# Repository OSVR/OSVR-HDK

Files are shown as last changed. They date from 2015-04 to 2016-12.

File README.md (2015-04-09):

OSVR HDK production files.

License agreement is as follows:

Module Developer Kit License 

This License (“License”) is offered to you by Razer Inc. and its affiliates (“Razer”), and governs your use of the Module Developer Kit. Please read this License carefully. By clicking “I Accept”, or by using the Module Developer Kit, you accept and agree to this License. This License constitutes a binding agreement between You and Razer. If you do not accept and agree to the License, you may not use the Module Developer Kit.

Definitions: a. Head-mounted Device (“HMD”) means a head-mounted screen device for the purpose of displaying virtual reality or multimedia applications, intended to be used in conjunction with the OSVR Project, as defined in this Agreement;
b. Intellectual Property Rights (“IPR”) means all rights in patents, patent disclosures, rights in designs, copyright, semi-conductor topography rights, integrated circuit layout design rights, utility models, rights in know-how, inventions, technologies, processes, techniques, methods, designs, drawings, plans, data, specifications, research and development, all copies and tangible embodiments or descriptions of any of the foregoing (in whatever form or medium), rights protecting trade secrets and confidential information, and other intellectual property rights, whether registered or unregistered and including applications for registration, and all rights of protection having equivalent or similar effect or character in any part of the world, but excluding any trademark rights;

c. Module Developer Kit (“MDK”) means the MDK made available from time to time by Razer or its licensees to the OSVR Project at www.osvr.com , that includes all drawings, technical specifications, system files, and packaged APIs. Where You utilize a HMD supplied by Razer, that HMD shall fall within the meaning of the MDK. For the avoidance of doubt, any HMD that is not supplied by Razer, or any technology that is not made available on the OSVR Project, is excluded from the meaning of MDK;

d. Module: any device or component that can be coupled to the HMD, but excluding the HMD;

e. Module Interface Technology: the portions of Modules that implement the MDK or are necessary for interoperability with the HMD;

f. “OSVR Project”: means the Open Source Virtual Reality Project made available by Razer that is the open hardware and software platform initiative located at www.osvr.com, for the development of a HMD;

g. Software: means all or any Source Code and Object Code that is made available at www.osvr.com or any other repository notified by Razer;

h. Source Code means the preferred form for making modifications, including but not limited to software source code, documentation source, and configuration files;

i. Object Code means any form resulting from mechanical transformation or translation of a Source Code, including but not limited to compiled object code, generated documentation, and conversions to other media types; and

j. “You” or “Your” means an individual or a legal entity, its subsidiaries or affiliated companies, that is exercising the rights granted by this License.

Subject to the terms and conditions of this License, Razer grants You a limited, worldwide, no-charge, royalty-free, revocable, non-assignable, non-sublicensable and non-exclusive right to use the IPR owned or controlled by Razer that reads on the MDK, the Modules and the Module Interface Technology, or any combinations thereof, for the purposes of:
(a) developing and testing Modules on the OSVR Project; and (b) creating modified works, in accordance with the purposes set out below.

You agree and acknowledge that the MDK, Modules or Module Interface Technology available on the OSVR Project are solely for the purposes of the OSVR Project and Your personal use. You may not use, sell or distribute the MDK, Modules or Module Interface Technology nor the IPR contained therein for any purposes whatsoever, whether for commercial gain or otherwise. Any attempts to do so will automatically terminate this License.

You agree and acknowledge that the IPR in the MDK, Modules or Module Interface Technology made available on the OSVR Project are owned or controlled by Razer or its licensors.

Except for the license granted herein to Razer, its licensees and assignees, You retain all rights to your IPR when you use the MDK. Through your participation in the OSVR Project, You agree to:

a. provide to Razer your IPR in the Modules or any modified works that may read on the MDK, Modules or Module Interface Technology for the OSVR Project. Your failure to comply with this requirement will automatically terminate this License; and b. grant Razer, Razer’s licensees and assignees a limited, worldwide, no-charge, royalty-free, irrevocable, and non-exclusive right to use Your IPR already existing or that may arise in any modified works that may read on the MDK, Modules or Module Interface Technology. You permit Razer to make, use, sell, distribute, modify and create modified works from Your IPR as described herein. Razer may also sub-license rights to other parties to make, use or sell Your IPR that may read on the MDK, Modules or Module Interface Technology as licensed herein.

You agree that You will waive your rights to injunctive or other equitable relief in relation to your IPR as licensed back in the preceding paragraph. You agree to not prevent nor enjoin Razer or any third party in any way from the manufacture, sale, distribution, import or export of any Modules or product or service that meets with the requirements of the MDK, Modules or Module Interface Technology.

Should you threaten or begin proceedings against Razer alleging patent infringement connected to the OSVR Project, the MDK, Modules or Module Interface Technology, Razer will, at its option, suspend or terminate this License granted to you.

Any software, namely Source Code or Object Code that is made available on the OSVR Project is excluded from the terms of this License. Such software will be governed by separate terms and conditions set out elsewhere at www.osvr.com .

You may not use the name of Razer, nor the names of Razer’s licensors, employees or contractors, to endorse or promote any products or services derived from the MDK without Razer’s express and prior written permission.

YOUR USE OF THE MDK AND ALL CONTENTS OF THE OSVR PROJECT SITE IS AND SHALL BE AT YOUR SOLE RISK. THE MDK AND OSVR PROJECT SITE AND ALL CONTENTS THEREON ARE PROVIDED “AS IS” AND WITHOUT EXPRESS OR IMPLIED WARRANTY OF ANY KIND. TO THE MAXIMUM EXTENT PERMITTED BY LAW, RAZER AND THEIR RESPECTIVE OFFICERS, DIRECTORS, EMPLOYEES, LICENSORS AND AGENTS DISCLAIM ALL WARRANTIES, EXPRESS OR IMPLIED, WITH RESPECT TO THE MDK AND OSVR PROJECT SITE, ALL CONTENTS THEREON, AND SUPPORT SERVICES, INCLUDING BUT NOT LIMITED TO ALL IMPLIED WARRANTIES OF MERCHANTABILITY, FITNESS FOR A PARTICULAR PURPOSE, NON-INFRINGEMENT AND TITLE. RAZER MAKES NO WARRANTY AS TO THE ACCURACY OR COMPLETENESS OF THE CONTENTS OF THE MDK OR THE OSVR PROJECT SITE, AND DOES NOT ENDORSE OR ASSUME LIABILITY FOR ANY DATA, PRODUCT OR SERVICE POSTED BY A THIRD PARTY THROUGH THE OSVR PROJECT SITE. RAZER ASSUMES NO LIABILITY OR RESPONSIBILITY FOR ANY BUGS, VIRUSES, OR OTHER MALWARE THAT MAY BE TRANSMITTED TO OR THROUGH THE OSVR PROJECT SITE, FOR ANY ERRORS, MISTAKES OR INACCURACIES IN CONTENT, OR FOR ANY LOSS OR DAMAGE INCURRED THAT RESULTS FROM THE USE OF ANY CONTENT MADE AVAILABLE IN ANY WAY IN THE MDK OR THROUGH THE OSVR PROJECT SITE.

IN NO EVENT SHALL RAZER, THEIR OFFICERS, DIRECTORS, EMPLOYEES, LICENSORS OR AGENTS BE LIABLE TO YOU FOR ANY SPECIAL, INCIDENTAL, INDIRECT, CONSEQUENTIAL OR PUNITIVE DAMAGES WHATSOEVER, INCLUDING THOSE RESULTING FROM LOSS OF USE, DATA OR PROFITS, HOWEVER CAUSED AND REGARDLESS OF THE THEORY OF LIABILITY, ARISING OUT OF OR IN CONNECTION WITH YOUR USE OF OR INABILITY TO USE THE MDK, EVEN IF RAZER HAS BEEN ADVISED OF THE POSSIBILITY OF SUCH DAMAGES. IN NO EVENT WILL RAZER’S LIABILITY EXCEED THE AMOUNT PAID BY YOU FOR A PRODUCT OR SERVICE.

All other intellectual property rights, trademarks and logos not included in the OSVR are expressly excluded from this License. “RAZER”, the Triple Headed Snake Logo, the names of Razer products, and graphics, logos, page headers, button icons, scripts, and service names may be trademarks, registered trademarks, trade dress or domain names of Razer. You may not use the foregoing in any manner that disparages or discredits Razer or is likely to cause confusion among customers. You may not use Razer’s trademarks and/or trade dress in connection with any product or service without Razer’s express written consent.

You agree to indemnify, defend and hold Razer, its affiliates, officers, directors, employees, licensees and agents harmless from and against any claims, actions, suits or proceedings, loss, cost, damages, liability and expense arising out of or relating to:

a. your use of the MDK, including but not limited to Your or any third party’s manufacture, use, sale, offer for sale or distribution of Your Modules; b. any Module you develop on the MDK that infringes the copyright, trademark, trade dress, trade secret, patent or any intellectual property right of any third party, or defames any person or infringes their rights of publicity or privacy; and c. any act or omission by You which is a breach of this License, or violates any law, regulation or rights of a third party.

You agree that Razer reserves the right at any time, and without prior notice, to modify or substitute components of the MDK, or to withdraw the MDK at any time at its sole discretion. Consequently, You acknowledge that future versions of the MDK may be incompatible with Modules developed on previous versions of the MDK.

Razer reserves the right to amend this License at any time, in its sole discretion. We will notify You of any material changes to the License by posting the new License terms on the www.osvr.com site. Please review these License terms regularly for any changes. The date of the last revision appears at the top of the License. Your continued use of the MDK subsequent to any changes to the License terms will signify your acceptance of the revised terms of License for those future MDK releases.

Without prior notice, Razer may terminate Your License if you violate or breach this License, or for any other reason. In the event of termination, the provisions of paragraph 5 shall continue for a period of twelve (12) months from the date of termination, and the provisions of paragraph 18 of this License shall survive.

You agree that the laws of the State of California, without regard to principles of conflict of laws, will govern this License and any dispute of any sort that might arise between you and Razer from your use of the MDK.

Any dispute relating to your use of the MDK shall be submitted to confidential arbitration in San Diego, California, except that, to the extent you have in any manner violated or threatened to violate Razer’s IPR, Razer may seek injunctive or other appropriate relief in any state or federal court, and you consent to exclusive jurisdiction and venue in such courts. Arbitration under this agreement shall be conducted under the rules then prevailing of the American Arbitration Association. The arbitrator's award shall be binding and may be entered as a judgment in any court of competent jurisdiction. To the fullest extent permitted by applicable law, no arbitration under this Agreement shall be joined to an arbitration involving any other party subject to this Agreement, whether through class arbitration proceedings or otherwise.

This License and other legal notices published by Razer at www.osvr.com from time to time shall constitute the entire agreement between You and Razer concerning the MDK. If any of the provisions of this License shall be deemed invalid, void, or for any reason unenforceable, that provision shall be deemed severable and shall not affect the validity and enforceability of any of the remaining provisions of this License, which shall continue in full force and effect. No waiver shall be deemed a further or continuing waiver, and Razer’s failure to assert any right under this License shall not constitute a waiver of such right. You agree that any cause of action arising out of or relating to the MDK must commence within one (1) year after the cause of action arises, and otherwise is permanently barred. You may not assign or transfer this License, but Razer may assign this License without restriction.

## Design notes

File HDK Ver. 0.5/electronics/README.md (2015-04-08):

Electrical files for OSVR Hacker Dev Kit first public release.

It includes:
Allegro Library files
Board files
Schematics in PDF
Complete EE BOM in XLS down to the last capacitor

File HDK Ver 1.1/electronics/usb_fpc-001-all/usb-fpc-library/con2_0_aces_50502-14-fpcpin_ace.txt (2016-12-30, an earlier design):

(DEVICE FILE: CON2_0_ACES_50502-14-FPCPIN_ACE)

PACKAGE 'ACES_50502-14-FPCPIN'
CLASS IC
PINCOUNT 14

PINORDER 'CON2_0_ACES_50502-14-FPCPIN_ACE' 1 10 11 12 13 14 2 3 4 5 6 7 8 9
FUNCTION G1 'CON2_0_ACES_50502-14-FPCPIN_ACE' 1 10 11 12 13 14 2 3 4 5 6 7 8 9

PACKAGEPROP PART_NAME CON2_0
PACKAGEPROP VALUE ACES_14PIN_FPC

END

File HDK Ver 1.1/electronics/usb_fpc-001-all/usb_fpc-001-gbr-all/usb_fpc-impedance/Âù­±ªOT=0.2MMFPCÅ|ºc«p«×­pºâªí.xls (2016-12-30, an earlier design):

板厚計算 | FPC＆手指疊構厚度計算表
料號： |  | 制令號： |  |  |  |  | 阻抗
 |  | 層別 | 手指1 | 結構圖 | 手指2 | FPC厚度(um) | Single End |  | Differential
 |  |  |  |  |  |  |  |  |  | 90+/-10%
 |  | C/L |  |  |  | 12.5
 |  | 膠(AD) |  |  |  | 25
 |  | 鍍銅 |  |  |  | 10
 |  | 銅(CU) |  | L1 |  | 18 |  |  |  | 5/6mil
 |  | 膠(AD) |  |  |  | 20
 |  | 基材(PI) |  |  |  | 25
 |  | 膠(AD) |  |  |  | 20
 |  | 銅(CU) |  | GND |  | 18
 |  | 鍍銅 |  |  |  | 10
 |  | 膠(AD) |  |  |  | 25
 |  | C/L |  |  |  | 12.5
 | 加總 |  |  |  |  | 196 |  | 0 | 0
 |  |  | 確認: |  |  |  |  | 設計:
保存期限：機種結束 |  |  |  |  |  |  |  |  | RDW7300107R01

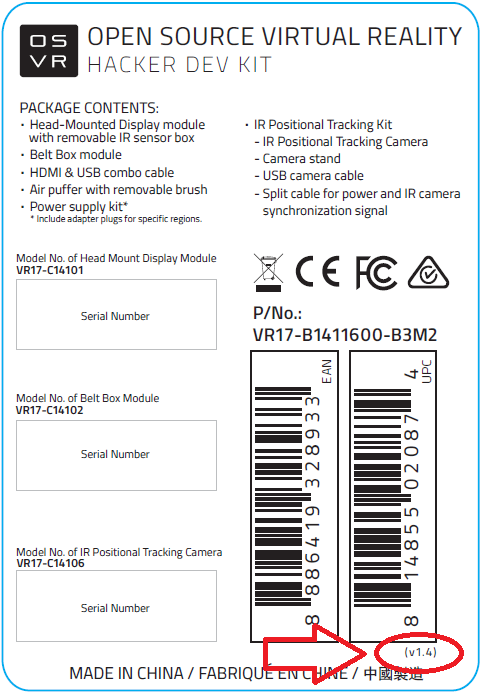
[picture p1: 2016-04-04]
HDK Ver 1.4/misc/1.4 label.png

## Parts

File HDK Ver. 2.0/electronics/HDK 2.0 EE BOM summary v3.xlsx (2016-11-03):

HDK2.0 EE BOM LIST
Description | Vendor | Vendor part number | Location | Category
PCB BARE PCB L:8 MAIN HMD BD 1.7mm FR4 EILEEN HDK TWO PANEL CNNT. | GUITECH | WPC8B8431N000 | NA | HMD board
RES RP 0 OHM 1% 1/16W CHIP #0603 | Ralec | RTT03R000FTP | R1003,R729,R801 | HMD board
RES RP 0 1% 1/10W CHIP #0402 | UniOhm | HP02WAF0000TCE | FB64,FB65,FB68,R1004,R608,R609,R610,R611,R612,R613,R614,R615,R616,R617,R618,R711,R712,R713,R714,R715,R730,R731,R732,R733,R734,R735,R736,R737,R738,R739,R740,R741,R838,R839,R840,R841,R842 | HMD board
RES RP 0 5% 1/8W CHIP #0805 | Ralec | RTT05000JTP | R746 | HMD board
RES RP 0 5% 1/10W 1A #0603 | UniOhm | 0603WAJ0000T5E | R567 | HMD board
RES RP 0 5% 1/10W CHIP #0402 | Ralec | RTH02000JTH | R1001,R107,R1106,R1107,R1108,R1109,R1110,R1111,R1112,R1113,R1114,R1115,R1116,R1117,R1118,R1119,R112,R1120,R1121,R1122,R1123,R1124,R1125,R1126,R1127,R1128,R1129,R113,R1130,R1131,R1132,R1133,R1134,R1135,R1136,R1137,R1138,R1139,R1140,R1141,R1142,R1143,R1144,R1145,R1149,R271,R336,R351,R468,R469,R516,R518,R539,R540,R62,R65,R66,R67,R742,R75,R768,R772,R775,R800,R83,R830,R86 | HMD board
RES RP 100 1% 1/10W CHIP #0402 | UniOhm | HP02WAF1000TCE | R303,R536,R751 | HMD board
RES RP 1K 1% 1/8W CHIP #0805 | Ralec | RTT051001FTP | R743,R745 | HMD board
RES RP 1K 1% 1/10W CHIP #0402 | UniOhm | HP02WAF1001TCE | R1091,R1096,R1097,R1098,R1099,R1103,R1104,R252,R440,R529,R55,R781,R802 | HMD board
RES RP 10K 1% 1/10W CHIP #0603 | UniOhm | 0603WAF1002T5E | R851 | HMD board
RES RP 10K 1% 1/10W CHIP #0402 | UniOhm | HP02WAF1002TCE | R106,R1100,R1101,R1105,R1151,R1152,R1160,R127,R19,R199,R207,R265,R266,R267,R268,R30,R309,R352,R524,R526,R527,R528,R542,R543,R544,R545,R558,R564,R568,R72,R744,R760,R761,R765,R770,R791,R795,R803 | HMD board
RES RP 100K 1% 1/10W CHIP #0603 | UniOhm | 0603WAF1003T5E | R509,R849 | HMD board
RES RP 100K 1% 1/10W CHIP #0402 | UniOhm | HP02WAF1003TCE | R286,R313,R514,R515,R522 | HMD board
RES RP 1M 1% 1/16W CHIP#0402 TA-I | Ralec | RTT021004FTH | R525,R64,R750 | HMD board
RES RP 1M 1% 1/10W CHIP #0603 GREEN | UniOhm | 0603WAF1004T5E | R848 | HMD board
RES RP 12K 1% 1/10W CHIP #0603 | UniOhm | 0603WAF1202T5E | R847 | HMD board | `
RES RP 12K 1% 1/10W CHIP #0402 | UniOhm | HP02WAF1202TCE | R523 | HMD board
RES RP 124K 1% 1/16W CHIP #0402 | Ralec | RTT021243FTH | R565 | HMD board
RES RP 120K 1% 1/10W CHIP #0603 | UniOhm | 0603WAF1203T5E | R846,R850 | HMD board
RES RP 13K 1% 1/10W CHIP #0402 | UniOhm | HP02WAF1302TCE | R91 | HMD board
RES RP 15 1% 1/4W CHIP #1206 | UniOhm | 1206W4F150JT5E | R1094,R1095,R1102 | HMD board
RES RP 150K 1% 1/16W CHIP #0402 | Ralec | RTT021503FTH | R728 | HMD board
RES RP 2K 1% 1/10W CHIP #0603 | UniOhm | 0603WAF2001T5E | R762 | HMD board
RES RP 20K 1% 1/16W CHIP #0402 | Ralec | RTT022002FTH | R1161,R1162,R122,R254,R700,R717,R825,R826 | HMD board
RES RP 20.5K 1% 1/10W CHIP #0402 | UniOhm | HP02WAF2052TCE | R37 | HMD board
RES RP 21.5K 1% 1/16W CHIP #0402 | Ralec | RTT022152FTH | R566 | HMD board
RES RP 2.1M 1% 1/16W CHIP #0402 | Ralec | RTT022104FTH | R510 | HMD board
RES RP 220 1% 1/10W CHIP #0402 | UniOhm | HP02WAF2200TCE | R455 | HMD board
RES RP 232K 1% 1/10W CHIP #0402 | UniOhm | HP02WAF2323TCE | R512 | HMD board
RES RP 24K 1% 1/16W CHIP #0603 "GREEN" | Ralec | RTT032402FTP | R844 | HMD board
RES RP 267K 5% 1/16W #0603 RTT032673FTP RALEC | Ralec | RTT032673FTP | R845 | HMD board
RES RP 33 1% 1/16W CHIP #0603 | UniOhm | 0603WGF330JT5E | R792,R793,R794,R796,R797,R798,R799,R804 | HMD board
RES RP 33 1% 1/10W CHIP #0402 | UniOhm | HP02WAF330JTCE | R115 | HMD board
RES RP 330 1% 1/10W CHIP #0402 | UniOhm | HP02WAF3300TCE | R52 | HMD board
RES RP 45.3K 1% 1/10W CHIP #0402 | UniOhm | HP02WAF4532TCE | R28 | HMD board
RES RP 4.7K 1% 1/10W CHIP #0603 | UniOhm | 0603WAF4701T5E | R220 | HMD board
RES RP 4.7K 1% 1/10W CHIP #0402 | UniOhm | HP02WAF4701TCE | R341,R353,R466,R467,R472,R511,R806,R94,R95,R96 | HMD board
RES RP 47K 1% 1/16W CHIP 0402 | Ralec | RTT024702FTH | R763,R764 | HMD board
RES RP 4.7 1% 1/10W CHIP #0603 | Ralec | RTT034R70FTP | R507,R508 | HMD board
RES RP 49.9 1% 1/10W CHIP #0402 | UniOhm | HP02WAF499JTCE | R1092,R316,R450,R63 | HMD board
RES RP 49.9K 1% 1/10W CHIP #0402 | UniOhm | HP02WAF4992TCE | R1093,R219,R222,R323,R453 | HMD board
RES RP 51K 1% 1/10W CHIP #0402 | UniOhm | HP02WAF5102TCE | R748,R749 | HMD board
RES RP 5R1 1% 1/16W CHIP #0402 | Ralec | RTT025R10FTH | R600,R601,R602,R603,R604,R605,R606,R607 | HMD board
RES RP 68.1K 1% 1/10W CHIP #0402 | UniOhm | HP02WAF6812TCE | R513 | HMD board
RES RP 78.7K 1% 1/16W CHIP #0402 | Ralec | RTT027872FTH | R186,R41,R84 | HMD board
RES RP 8.25K 1% 1/10W CHIP #0402 | UniOhm | HP02WAF8251TCE | R193 | HMD board
CAP CC 10uF 10% 10V X5R CHIP #0603 | YAGEO | CC0603KRX5R6BB106 | C704,C706,C707,C709,C711,C712,C714,C715,C718,C814,C816,C817,C819,C821,C822,C824,C825,C828 | HMD board
CAP CS TANT 10uF ±10% 10V CASE-A 3216-18 T494A106K010AT KEMET | KEMET | T494A106K010AT | C42 | HMD board
CAP CK 10uF 10% 25V X5R CHIP #1206 | YAGEO | CC1206KKX5R8BB106 | C647,C648,C649,C657,C658,C659,C660 | HMD board
CAP CK 10uF ±20% 10V X5R #0603 LMK107BBJ106MALT TAIYO YUDEN | TAIYO YUDEN | LMK107BBJ106MALT | C255,C52,C624,C629,C643,C644,C758 | HMD board
CAP CC 100pF 5% 50V NPO CHIP #0402 | YAGEO | CC0402JRNPO9BN101 | C702,C705,C708,C710,C713,C716,C717,C719,C812,C815,C818,C820,C823,C826,C827,C829 | HMD board
CAP CC 0.01uF 10% 50V X7R #0402 GREEN | YAGEO | CC0402KRX7R9BB103 | C144,C209,C244,C581,C603,C736,C737,C738,C741,C742,C743,C746,C747,C748,C749 | HMD board
CAP CC 0.1uF 10% 16V X7R CHIP #0402 | YAGEO/ WALSIN | CC0402KRX7R7BB104/ 0402B104K160CT | C703,C813 | HMD board
CAP CC 0.1uF 10% 25V X5R #0402 | YAGEO/ WALSIN | CC0402KRX5R8BB104/ 0402X104K250CT | C10,C119,C127,C159,C169,C18,C201,C208,C231,C285,C303,C306,C54,C575,C579,C580,C584,C60,C604,C605,C609,C610,C612,C614,C615,C616,C617,C618,C619,C620,C621,C622,C623,C625,C626,C627,C628,C633,C652,C732,C733,C735,C739,C740,C744,C745,C750,C751,C755,C757,C76,C837,C9 | HMD board
CAP CC 0.1uF 10% 50V X7R #0603 | YAGEO | CC0603KRX7R9BB104 | C100,C145,C175,C2,C220,C28,C602,C632,C761,C762 | HMD board
CAP CK 1Uf 10% 6.3V X5R #0402 | YAGEO | CC0402KRX5R5BB105 | C701,C720,C721,C729,C731,C807,C808,C809 | HMD board
CAP CC 1uF 10% 10V X5R #0402 | YAGEO | CC0402KRX5R6BB105 | C20,C5,C72,C760 | HMD board
CAP CK 1uF 10% 10V X5R CHIP #0603 | YAGEO | CC0603KRX5R6BB105 | C638,C722,C723,C805,C811,C838 | HMD board
CAP CC 1uF 10% 25V X5R #0603 | YAGEO | CC0603KRX5R8BB105 | C653 | HMD board
CAP CK 12PF 5% 50V NPO #0402 | YAGEO | CC0402JRNPO9BN120 | C611 | HMD board
CAP CC 15PF 5% 50V NPO CHIP #0402 | YAGEO | CC0402JRNPO9BN150 | C613 | HMD board
CAP CC 0.015uF ±10% 10V X5R #0402 C0402C153K8PACTU KEMET | KEMET | C0402C153K8PACTU | C157,C298,C545 | HMD board
CAP CC 18pF 5% 50V NPO CHIP #0402 | YAGEO | CC0402JRNPO9BN180 | C31,C32 | HMD board
CAP CK 22uF 10% 10V X7R CHIP #1206 | YAGEO | CC1206KKX7R6BB226 | C654,C655,C726 | HMD board
CAP CK 22uF ±20% 35V X5R #1206 C3216X5R1V226M160AC "TDK" | TDK | C3216X5R1V226M160AC | C1,C3 | HMD board
CAP CS TANT 220uF ±20% 6.3V CASE-B 3528-21 T55B227M6R3C0070 "VISHAY" | VISHAY | T55B227M6R3C0070 | C700,C727,C728 | HMD board
CAP CC 22pF 5% 50V NPO #0603 | YAGEO | CC0603JRNPO9BN220 | C650,C830,C836 | HMD board
CAP CC 2200pF 10% 50V X7R CHIP #0402 | YAGEO | CC0402KRX7R9BB222 | C645,C646 | HMD board
CAP CK 2700pF 10% 50V X7R #0402 | YAGEO | CC0402KRX7R9BB272 | C25 | HMD board
CAP CC 33pF 5% 50V NPO #0402 "GREEN" | YAGEO | CC0402JRNPO9BN330 | C120,C61 | HMD board
CAP CC 3300pF 10% 50V X7R CHIP #0603 | YAGEO | CC0603KRX7R9BB332/ 0603B332K500CT | C656 | HMD board
CAP CC 390pF 5% 50V NPO #0402 | YAGEO | CC0402JRNPO9BN391 | C123,C19,C67 | HMD board
CAP CK 47uF 20% 6.3V X5R CHIP #0805 "Murata" GRM21BR60J476ME15L | Murata | GRM21BR60J476ME15L | C111,C113,C29,C36,C49,C51 | HMD board
CAP CK 47uF ±20% 10V X5R #1206 LMK316ABJ476ML-T TAIYO YUDEN | TAIYO YUDEN | LMK316ABJ476ML-T | C1011,C1012,C1013,C1014,C1015,C1016,C104,C108,C129,C34,C38,C41,C43,C6,C81,C833,C834,C835 | HMD board
CAP CC 470pF 5% 50V NPO #0603 | YAGEO | CC0603JRNPO9BN471 | C136 | HMD board
CAP CC 4700PF 10% 50V X7R #0402 | YAGEO | CC0402KRX7R9BB472 | C57 | HMD board
CAP CC 4.7uF 10% 10V X5R CHIP #0402 | YAGEO | CC0402KRX5R6BB475 | C724,C810 | HMD board
CAP CC 56pF 5% 50V NPO CHIP 0402 | YAGEO | CC0402JRNPO9BN560 | C23 | HMD board
CAP CC 8200pF 10% 25V X7R #0402 | YAGEO | CC0402KRX7R8BB822 | C116 | HMD board
INDUCTOR COMMON MODE CHOKE COIL 90OHM 150mA DLP11SA900HL2L SMD "MURATA" | MURATA | DLP11SA900HL2L | L21,L22 | HMD board
INDUCTOR BEAD 100±25% Ohm 2.5A PBY160808T-101Y-N CHILISIN #0603 | 奇力新 | PBY160808T-101Y-N | FB11,FB23,FB24,FB4,FB62,FB63,FB66,FB67,FB70,FB8 | HMD board
INDUCTOR BEAD 80±25% Ohm 5A GMLB-201209-0080P-N8B MAGLAYERS #0805 | 美磊 | GMLB-201209-0080P-N8B | FB16,FB6,FB7,L23 | HMD board
BEAD UPB321611T-121Y-N 6A 120ohm "CHILISIN" | 奇力新 | UPB321611T-121Y-N | FB1,FB2,FB56,FB61 | HMD board
INDUCTOR 10uH 20% 1A MLH-YT12N100M-O1 "MAGLAYERS" | 美磊 | MLH-YT12N100M-O1 | L31,L34 | HMD board
INDUCTOR POWER SEALED 1.2uH 20% 3.3A LVS404026-1R2,"Chilisin" | 奇力新 | LVS404026-1R2 | L36,L37 | HMD board
INDUCTOR INDCTR 3.3uH 20% 6A MMD-06CZ-3R3M-V1 SMD "MAGLAYERS" | 美磊 | MMD-06CZ-3R3M-V1 | L25 | HMD board
INDUCTOR 4.7uH 20% 1.5A MLV-YT12N4R7M-O1 "MAGLAYERS" | 美磊 | MLV-YT12N4R7M-O1 | L30,L32,L33,L35 | HMD board
INDUCTOR POWER CHOKE 4.7uH 20% 6A MHCI05030-4R7M-R8 "CHILISIN" | 奇力新 | MHCI05030-4R7M-R8 | L13 | HMD board
INDUCTOR POWER CHOKE 5.6uH 20% 4.5A MHCI05020-5R6M-R8 SMD "CHILISIN" | 奇力新 | MHCI05020-5R6M-R8 | L5,L9 | HMD board
FUSE 3A 15V TUV SMD2920P300TF/15 "POLYTRONICS" | Kunshan Polystar Electronics Co.ltd | SMD2920P300TF/15 |  | HMD board
XTAL 8MHz ±30ppm CL=18pF 5*3.2mm SMD E5FA8E000000GE "HOSONIC" | 鴻星 | E5FA8E000000GE | Y1 | HMD board
XTAL 25MHz ±10ppm CL=10pF 3.2*2.5mm SMD E3SB25E00000LE "HOSONIC" | 鴻星 | E3SB25E00000LE | Y6 | HMD board
XTAL SMD CRYSTAL OSCILLATOR 48MHZ 1.8V D3SX48E00000CE 3.2*2.5mm "HOSONIC" | 鴻星 | D3SX48E00000CE | Y7 | HMD board
TRNSTR 2N7002-7-F N-CHANNEL ENHANCEMENT SOT-23 "DIODES" | Diodes | 2N7002-7-F | Q21,Q23,Q41 | HMD board
MOSFET DUAL N-CH 2N7002DW-7-F VDSS/60V VGSS/20V ID/0.115A SOT363 "DIODES" | Diodes | 2N7002DW-7-F | Q29 | HMD board
TRNSTR DMP2160U-7 P-CHANNEL ENHANCEMENT MODE MOSFET SOT-23 | Diodes | DMP2160U-7 | Q33,Q35,Q37 | HMD board
XTOR NPN MMBT2222A-7-F 600mA/40V SOT-23 DIODES | Diodes | MMBT2222A-7-F | Q11,Q32,Q7 | HMD board
TRNSTR MOSFET SIS434DN-T1-GE3 N-CHANNEL 40V (D-S) POWERPAK 1212-8 "VISHAY" | Vishay | SIS434DN-T1-GE3 | Q19,Q20,Q34,Q36,Q38 | HMD board
DIODE SURFACE MOUNT FAST SWITCHING DIODE 75V 1N4148WS-7-F SOD323 DIODES | Diodes | 1N4148WS-7-F | D7 | HMD board
DIODE SCHOTTKY 1N5819HW-7-F 1A/40V SOD123 DIODES | Diodes | 1N5819HW-7-F | D13,D14,D15 | HMD board
DIODE TVS DIOIDE ARRAY 6V 1 CHANNEL LOW CAPACITANCEVS D5V0F1U2LP-7B X1-DFN1006-2 DIODES | Diodes | D5V0F1U2LP-7B | ESD13,ESD14,ESD21 | HMD board
DIODE ZENER MMSZ5227B-7-F 3.42~3.78V SOD-123 DIODES | Diodes | MMSZ5227B-7-F | D6 | HMD board
DIODE ZENER 14.25V~15.75V 0.2W MMSZ5245BS-7-F SOD-323 DIODES | Diodes | MMSZ5245BS-7-F | D9 | HMD board
ESD DIODE POLYMERIC PGB1010603NR 0603 "LITTELFUSE" | Littlefuse | PGB1010603NR | ESD18,ESD22,ESD5,ESD8 | HMD board
ESD DIODE 5V TVS ARRAY RCLAMP0524PA SLP2510P8 'SEMTECH" | Semtech | RCLAMP0524PA | U6,U8 | HMD board
DIODE TVS ARRAY RCLAMP0502A.TCT LOW CAPACITANCE SC89 "SAMTECH" | Samtech | RCLAMP0502A.TCT | U34 | HMD board
DIODE TVS 600W 13V SMB SMBJ13CA-13-F "DIODES" | Diodes | SMBJ13CA-13-F | D1 | HMD board
DIODE LED GREEN SML-LX0603GW-TR #0603 LUMEX GREEN | Lumex | SML-LX0603GW-TR | LD11,LD13,LD16,LD17,LD4,LD5,LD8 | HMD board
CNNT PIN M 5P 1.25mm ST/DIP TU1252WNV-05 "TYU" | 唐虞 | TU1252WNV-05 | J10 | HMD board
CNNT PIN M 8P 1mm RA/SMT TU1001WNR-1x08S-A "TYU" | 唐虞 | TU1001WNR-1x08S-A | J66 | HMD board
CNNT PIN M 10P 1.27mm ST/SMT N123-1-10-2-30/10/17-G1 "KINGMATE" | 大幃 | N123-1-10-2-30/10/17-G1 | J6 | HMD board
CNNT PIN M 10P 0.8mm RA/SMT 50208-01001-001 "ACES" | 宏致 | 50208-01001-001 | J69 | HMD board
CNNT FPC 11P P=0.5 mm JS-1191PSDR-11G | 喬訊 | JS-1191PSDR-11G | J101 | HMD board
CNNT FPC F 14P 0.5mm RA/SMT 50502-01401-002 "ACES" | 宏致 | 50502-01401-002 | J22 | HMD board
CNNT FPC F 20P 0.5mm RA/SMT 51652-0200N-001 "ACES" | 宏致 | 51652-0200N-001 | J68 | HMD board
CNNT 30P 1.0mm RA/SMT 20389-Y30E-02 "I-PEX" | I-PEX | 20389-Y30E-02 | J1 | HMD board
CNNT FFC 39P P=0.3 mm FH35C-39S-0.3HW(50) | Hirose | FH35C-39S-0.3HW(50) | J20,J71 | HMD board
IC 74LVC1G08W5-7 SINGLE 2-INPUT OPSITIVE-AND GATE SOT-25 "DIODES" | Diodes | 74LVC1G08W5-7 | U35 | HMD board
IC 300mA LOW NOISE CMOS LDO REGULATOR AP2127K-1.8TRG1 SOT23-5 "DIODES" | Diodes | AP2127K-1.8TRG1 | U53,U60 | HMD board
IC AP2127K-3.0TRG1 300mA LOW NOISE CMOS LDO REGULATOR SOT23-5 "DIODES" | Diodes | AP2127K-3.0TRG1 | U54,U61 | HMD board
IC ACC GYR MAG SENSOR WITH 32BIT MCU BNO070 SMD "BOSCH" | BOSCH | BNO070 | U41 | HMD board
IC G632L293TC1U MICROPROCESSOR SUPERVISORY RESET CIRCUIT 3.3V SOT-143 "GMT" | 致新科技股份有限公司 | G632L293TC1U | U7 | HMD board
IC LTC4365IDDB#TRPBF OVP UVP AND REVERSE SUPPLY PROTECTION DFN8 "LINEAR TECHNOLOGY" | Linear | LTC4365IDDB#TRPBF | U45 | HMD board
IC SY8821SAC SYNCHRONOUS STEP DOWN DC-DC REGULATOR 5.5V 2MHz DUAL 1.0A&1.5A DFN2x1.5-8 "Silergy" | Silergy | SY8821SAC | U63 | HMD board
IC TC358870XBG HDMI TO DUAL MIPI DSI BRIDGE CONVERT- HDCP KEY,P-VFBGA80-0707-0.65-001"TOSHIBA" | TOSHIBA | TC358870XBG | U57 | HMD board
IC TPS54478RTER 2.95-V to 6-V INPUT, 4-A OUTPUT, 2-MHz, SYNCHRONOUS STEP-DOWN WQFN16 "TI" | TI | TPS54478RTER | U16,U29,U4 | HMD board
IC TPS54427DDAR 4-A SINGLE SYNCHRONOUS STEP DOWN SWITCHER SO8 "TI" | TI | TPS54327DDAR | U51 | HMD board
IC TPS65632RTER TRIPLE OUTPUTS AMOLED DISPLAY POWER SUPPLY QFN16 "TI" | TI | TPS65632RTER | U52,U62 | HMD board
IC TXS0104ERGYR 4-BIT BIDIRECTIONAL VOLTAGE-LEVEL TRANSLATOR VQFN14-EP "TI" | TI | TXS0104ERGYR | U55 | HMD board
IC 4-Port SS/HS USB Hub Controller USB5534B-5000JZX QFN64 "MICROCHIP" | Microchip | USB5534B-5000JZX | U46 | HMD board
IC 8/16-BIT MICROCONTROLLER ATXMEGA256A3BU-MH 64M2(QFN64) "ATMEL" | ATMEL | ATXMEGA256A3BU-MH | U12 | HMD board
SWITCH TACTILE SWITCH 4*2.5*1.6mm SMD B3U-1000P-B "OMRON" | OMRON | B3U-1000P-B | SW1,SW2 | HMD board
EMI SMD SPRING B8G-20*40*037 | CATERON | B8G-20*40*037 | T1,T2 | HMD board
PCB BARE PCB L:4 USB CONVERT BD 1.2mm FR4 FOR EILEEN HDK 2.0 | GUITECH | WPC8B4432N000 | NA | USB board
RES RP 0 1% 1/16W CHIP #0402 | Ralec | RTT02000FTH | R1000,R1001,R1002,R1003 | USB board
CAP CS TANT 220uF ±20% 6.3V CASE-B 3528-21 T55B227M6R3C0070 "VISHAY" | VISHAY | T55B227M6R3C0070 | C1000 | USB board
CAP CC 470pF 10% 50V X7R #0402 | YAGEO | CC0402KRX7R9BB471 | C1001 | USB board
CNNT 9P USB 3.0 FEMALE RA/DIP 2UB4006-400101F "SINGATRON" | 信音 | 2UB4006-400101F | CN100 | USB board
CNNT FPC 11P P=0.5 mm JS-1191PSDR-11G | 喬訊 | JS-1191PSDR-11G | J101 | USB board
PCB BARE PCB L:6 BELT BOX BD 1.2mm FR4 EILEEN | GUITECH | WPC8B6349N100 | NA | BB board
RES RP 0 1% 1/16W CHIP #0402 | Ralec | RTT02000FTH | R10,R11,R19,R20,R26,R27,R28,R46,R47,R48,R49,R50,R51,R7,R75,R79,R84 | BB board
RES RP 0 1% 1/10W CHIP #0402 | UniOhm | HP02WAF0000TCE | R317,R320,R321,R337,R344,R345,R371,R372,R373,R382,R383 | BB board
RES RP 0 5% 1/10W 1A #0603 | UniOhm | 0603WAJ0000T5E | R3,R32,R68 | BB board
RES RP 100 OHM 1% 1/16W 0402 | Ralec | RTT021000FTH | R77 | BB board
RES RP 10K 1% 1/16W CHIP #0402 | Ralec | RTT021002FTH | R102,R29,R30,R33,R41,R43,R44,R56,R58,R59,R60,R63,R65,R66,R67,R70,R72,R73,R89,R99 | BB board
RES RP 100K 1% 1/16W CHIP #0402 | Ralec | RTT021003FTH | R37,R42,R45,R54,R55,R57 | BB board
RES RP 1M 1% 1/16W CHIP#0402 TA-I | Ralec | RTT021004FTH | R39 | BB board
RES RP 115 1% 1/16W CHIP #0402 | Ralec | RTT021150FTH | R6 | BB board
RES RP 124K 1% 1/16W CHIP #0402 | Ralec | RTT021243FTH | R87 | BB board
RES RP 130K 1% 1/16W CHIP #0402 | Ralec | RTT021303FTH | R62 | BB board
RES RP 147 1% 1/16W CHIP #0402 | Ralec | RTT021470FTH | R9 | BB board
RES RP 187 1% 1/16W CHIP #0402 | Ralec | RTT021870FTH | R8 | BB board
RES RP 21.5K 1% 1/16W CHIP #0402 | Ralec | RTT022152FTH | R88 | BB board
RES RP 22 1% 1/16W CHIP #0402 | Ralec | RTT0222R0FTH | R52,R53 | BB board
RES RP 2.2K 5% 1/16W CHIP #0402 | Ralec | RTT02222JTH | R1,R2,R74 | BB board
RES RP 240K 1% 1/16W CHIP #0402 | Ralec | RTT022403FTH | R31,R34 | BB board
RES RP 30Kohm 1% 1/16W CHIP #0402 | Ralec | RTT023012FTH | R35 | BB board
RES RP 33K 1% 1/16W CHIP #0402 | Ralec | RTT023302FTH | R82 | BB board
RES RP 39Kohm 1% 1/16W CHIP #0402 | Ralec | RTT023902FTH | R40 | BB board
RES RP 4.7K 1% 1/10W CHIP #0402 | UniOhm | HP02WAF4701TCE | R15,R17,R22,R24 | BB board
RES RP 4.7K 5% 1/16W CHIP #0402 | Ralec | RTT02472JTH | R14,R18,R282,R283,R64 | BB board
RES RP 47K 1% 1/16W CHIP 0402 | Ralec | RTT024702FTH | R104,R105 | BB board
RES RP 4.99K 1% 1/10W CHIP #0603 "GREEN" | Ralec | RTT034991FTP | R4 | BB board
RES RP 5.1K 1% 1/16W CHIP #0402 RM04FTN5101 "大毅" | Ralec | RTT025111FTH | R36,R69,R71 | BB board
RES RP 5R1 1% 1/16W CHIP #0402 | Ralec | RTT025R10FTH | R85,R86 | BB board
RES RP 680 1% 1/16W #0402 | Ralec | RTT026800FTH | R38 | BB board
RES RP 750 1% 1/16W CHIP #0402 | Ralec | RTT027500FTH | R5 | BB board
RES RP 80.6K 1% 1/16W CHIP #0402 | Ralec | RTT028062FTH | R61 | BB board
CAP CC 10uF 10% 10V X5R CHIP #0603 | YAGEO | CC0603KRX5R6BB106 | C48,C50,C52,C55,C57,C63,C66,C71,C75 | BB board
CAP CK 10uF 10% 10V LOW PROFILE X5R FOR PK102 #0805 | YAGEO | CC0805KKX5R6BB106 | C10,C12,C28,C36,C37,C38 | BB board
CAP CK 10uF 10% 25V X5R CHIP #1206 | YAGEO | CC1206KKX5R8BB106 | C84,C89,C96 | BB board
CAP CS TANT 100uF ±20% 6.3V CASE-B 3528-21 T55B107M6R3C0035 "VISHAY" | VISHAY | T55B107M6R3C0035 | EC1 | BB board
CAP CC 100pF 5% 50V NPO CHIP #0402 | YAGEO | CC0402JRNPO9BN101 | C80,C81 | BB board
CAP CC 0.1uF 10% 16V X7R CHIP #0402 | YAGEO/ WALSIN | CC0402KRX7R7BB104/ 0402B104K160CT | C1,C16,C17,C18,C19,C2,C20,C21,C22,C23,C24,C25,C26,C29,C3,C30,C31,C32,C34,C4,C45,C46,C49,C5,C54,C56,C58,C59,C6,C60,C62,C64,C65,C67,C7,C72,C76,C79,C8,C9,C93 | BB board
CAP CC 0.1uF 10% 50V X7R #0402 GRM155R71H104KE14D "MURATA" | MURATA | GRM155R71H104KE14D | C86 | BB board
CAP CK 1Uf 10% 6.3V X5R #0402 | YAGEO | CC0402KRX5R5BB105 | C40,C42,C53,C61,C69,C70,C73,C95 | BB board
CAP CK 1uF 10% 10V X5R CHIP #0603 | YAGEO | CC0603KRX5R6BB105 | C11,C13 | BB board
CAP CC 1uF 10% 25V X5R #0603 | YAGEO | CC0603KRX5R8BB105 | C82 | BB board
CAP CC 15PF 5% 50V NPO CHIP #0402 | YAGEO | CC0402JRNPO9BN150 | C47 | BB board
CAP CC 18pF 5% 50V NPO CHIP #0402 | YAGEO | CC0402JRNPO9BN180 | C51 | BB board
CAP CK 22uF 10% 10V X7R CHIP #1206 | YAGEO | CC1206KKX7R6BB226 | C87,C90 | BB board
CAP CK 22uF 10% 10V X5R CHIP #0805 C2012X5R1A226KT TDK | TDK | C2012X5R1A226KT | C33 | BB board
CAP CS TANT 220uF ±20% 6.3V CASE-B 3528-21 T55B227M6R3C0070 "VISHAY" | VISHAY | T55B227M6R3C0070 | C14,C43 | BB board
CAP CC 22pF 5% 50V NPO #0603 | YAGEO | CC0603JRNPO9BN220 | C35,C91 | BB board
CAP CC 2200pF 10% 50V X7R CHIP #0402 | YAGEO | CC0402KRX7R9BB222 | C88,C92 | BB board
CAP CC 2.2uF 10% 16V X5R #0603 | YAGEO | CC0603KRX5R7BB225 | C74,C77,C78 | BB board
CAP CC 27pF 5% 50V NPO CHIP #0402 | YAGEO | CC0402JRNPO9BN270 | C39,C41 | BB board
CAP CC 3300pF 10% 50V X7R CHIP #0603 | YAGEO | CC0603KRX7R9BB332/ 0603B332K500CT | C83 | BB board
CAP CC 470pF 10% 50V X7R #0402 | YAGEO | CC0402KRX7R9BB471 | C15,C44 | BB board
CAP CK 4.7uF 10% 6.3V X5R CHIP #0603 C1608X5R0J475K TDK | TDK | C1608X5R0J475K | C27 | BB board
CAP CK 4.7uF 10% 6.3V X5R CHIP #0603 CC0603KKX5R5BB475 YAGEO | YAGEO | CC0603KKX5R5BB475 | C27 | BB board
INDUCTOR COMMON MODE CHOKE COIL SMD MCI-2012H-900 GREEN "maglayers" | 美磊 | MCI-2012H-900 | L12,L13,L14,L15,L16,L17,L18,L19 | BB board
INDUCTOR BEAD 600 OHM 300mA BK1005HS601-T "TAIYO YUDEN" #0402 | TAIYO YUDEN | BK1005HS601-T | FB1,FB2,FB3 | BB board
INDUCTOR BEAD 80±25% Ohm 5A GMLB-201209-0080P-N8B MAGLAYERS #0805 | 美磊 | GMLB-201209-0080P-N8B | L11 | BB board
INDUCTOR BEAD 100±25% Ohm 1.2A PBY100505T-101Y-N CHILISIN #0402 | 奇力新 | PBY100505T-101Y-N | FB4,FB5 | BB board
INDUCTOR INDCTR 10uH 20% 1.4A LVS404018-100M-N SMD "CHILISIN" | 奇力新 | LVS404018-100M-N | L4 | BB board
INDUCTOR INDCTR 3.3uH 20% 6A MMD-06CZ-3R3M-V1 SMD "MAGLAYERS" | 美磊 | MMD-06CZ-3R3M-V1 | L10 | BB board
XTAL 25MHz ±20ppm CL=18pF 3.2*2.5mm SMD E3SB25E000020E "HOSONIC" | 鴻星 | E3SB25E000020E | Y1 | BB board
XTAL 48MHz ±30ppm CL=18pF 5*3.2mm SMD E5FA48E000007E "HOSONIC" | 鴻星 | E5FA48E000007E | Y2 | BB board
MOSFET N-CHANNEL BSS138 SOT-23 "FAIRCHILD" | Fairchild | BSS138 | Q1,Q6 | BB board
TRNSTR N-CHANNEL 20V MOSFET RUM001L02T2CL VMT3 "ROHM" | ROHM | RUM001L02T2CL | Q2,Q3,Q4 | BB board
TRNSTR N-CHANNEL 20V MOSFET SI2312CDS-T1-GE3 SOT23 "VISHAY" | Vishay | SI2312CDS-T1-GE3 | Q5 | BB board
ESD-PROTECTION LOW CAPACITANCE TVS DIODE ARRAY D5V0F4U10LP-7 DFN2510-10,"DIODES" | Diodes | D5V0F4U10LP-7 | U10,U19,U4 | BB board
DIODE TVS DIODE ARRAY 2 CHANNEL 6V DRTR5V0U2SR-7 SOT143 "DIODES" | Diodes | DRTR5V0U2SR-7 | U18,U5,U9 | BB board
ESD DIODE POLYMERIC PGB1010603NR 0603 "LITTELFUSE" | Littlefuse | PGB1010603NR | ESD1,ESD2 | BB board
ESD DIODE 5V TVS ARRAY RCLAMP0524PA SLP2510P8 'SEMTECH" | Semtech | RCLAMP0524PA | U16,U17,U21,U23 | BB board
CNNT 7P FEMALE 3.5mm PHONE JACK RA/DIP 2SJ2284-102592 "SINGATRON" | 信音 | 2SJ2284-102592 | J6 | BB board
CNNT 7P POWER JACK RA/DIP 2DC3064-010111F "SINGATRON" | 信音 | 2DC3064-010111F | J3 | BB board
CNNT 9P 2.0mm USB 3.0 A TYPE FEMALE RA/DIP 2UB1585-000121F "SINGATRON" | 信音 | 2UB1585-000121F | J4 | BB board
CNNT MICRO USB 3.0 10P RT/SMT USB3110-30-A "GCT" | GCT | USB3110-30-A | J5 | BB board
CNNT HDMI F 19PIN 1mm RT/DIP 2HE1718-000111F "SINGATRON" | 信音 | 2HE1718-000111F | J1 | BB board
CNNT 36P 0.5mm RA/SMT ST60-36P "HIROSE" | Hirose | ST60-36P(30) | J2 | BB board
IC 300mA LOW NOISE CMOS LDO REGULATOR AP2127K-1.8TRG1 SOT23-5 "DIODES" | Diodes | AP2127K-1.8TRG1 | U12 | BB board
IC AP2186SG-13 1.5A DUAL CHANNEL CURRENT-LIMITED POWER SWITCH SO8 "DIODES" | Diodes | AP2186SG-13 | U8 | BB board
IC AZ1117CD-ADJTRG1 1A LOW DROPOUT LINEAR REGULATOR TO252-2 "DIODES" | Diodes | AZ1117CD-ADJTRG1 | U3 | BB board
IC AUDIO DSP I2S/I2C/USB CODEC WITH CLASS-D AMP CX20705 QFN76 "CONEXANT" | CONEXANT | CX20705 | U11 | BB board
IC G1117T63UF 1A ADJUSTABLE LDO SOT223 "GMT" | GMT | G1117T63Uf | U2 | BB board
IC USB3.0 HUB CONTROLLER GL3522-OTY22 QFN76 "GENESYS LOGIC" | GenesysLogic | GL3522-OTY22 | U7 | BB board
IC PS8407ATQFN40GTR2-A1 JITTER CLEANING HDMI LEVEL SHIFTER AND REPEATER TQFN40 "PARADE" | Parade | PS8407ATQFN40GTR2-A1 | U1 | BB board
IC 3-A SINGLE SYNCHRONOUS STEP DOWN SWITCHER TPS54327DDAR SO8 "TI" | TI | TPS54327DDAR | U14 | BB board
IC EEPROM 256KBIT BR24G256FJ-3GTE2 SOP-J8 "ROHM" | ROHM | BR24G256FJ-3GTE2 | U13 | BB board
IC SERIAL FLASH 512K BIT W25X05CLSNIG SOIC8 "WINBOND" | Winbond | W25X05CLSNIG | U6 | BB board
PCB BARE PCB L:4 IR BD 1.2mm FR4 ADD UPGRADED CNNT EILEEN | GUITECH | WPC8B4327N200 | NA | IR board
RES RP 0 1% 1/16W CHIP #0402 | Ralec | RTT02000FTH | R14,R19,R20,R28,R30 | IR board
RES RP 0 5% 1/8W CHIP #0805 | Ralec | RTT05000JTP | R1,R2,R3,R8 | IR board
RES RP 0 5% 1/10W 1A #0603 | UniOhm | 0603WAJ0000T5E | R4 | IR board
RES RP 10K 1% 1/16W CHIP #0402 | Ralec | RTT021002FTH | R11,R12,R7,R9 | IR board
RES RP 120ohm1% 1/16W CHIP #0402 | Ralec | RTT021200FTH | R25 | IR board
RES RP 20.5K 1% 1/10W CHIP #0402 | UniOhm | HP02WAF2052TCE | R13 | IR board
RES RP 30.1K 1% 1/16W CHIP #0402 | Ralec | RTT023012FTH | R17 | IR board
RES RP 330 1% 1/10W CHIP #0402 | UniOhm | HP02WAF3300TCE | R21,R22 | IR board
RES RP 36.5K 1% 1/16W CHIP #0402 | Ralec | RTT023652FTH | R5 | IR board
RES RP 4.99K 1% 1/16W CHIP #0402 | Ralec | RTT024991FTH | R24 | IR board
RES RP 52.3K 1% 1/16W CHIP #0402 | Ralec | RTT025232FTH | R16 | IR board
RES RP 75R 1% 1/16W CHIP #0402 | Ralec | RTT0275R0FTH | R26 | IR board
RES RP 78.7K 1% 1/16W CHIP #0402 | Ralec | RTT027872FTH | R10 | IR board
CAP CC 10uF 10% 10V X5R CHIP #0603 | YAGEO | CC0603KRX5R6BB106 | C25,C26 | IR board
CAP CC 0.1uF 10% 16V X7R CHIP #0402 | YAGEO/ WALSIN | CC0402KRX7R7BB104/ 0402B104K160CT | C1,C12,C17,C18,C24,C27,C3,C31,C4,C5,C7,C8,C9 | IR board
CAP CC 0.1uF 10% 25V X5R #0402 | YAGEO/ WALSIN | CC0402KRX5R8BB104/ 0402X104K250CT | C14 | IR board
CAP CC 0.015uF 10% 16V X7R CHIP #0402 | YAGEO | CC0402KRX7R7BB152 | C19 | IR board
CAP CS TANT 220uF ±20% 6.3V CASE-B 3528-21 T55B227M6R3C0070 "VISHAY" | VISHAY | T55B227M6R3C0070 | C2 | IR board
CAP CK 2700pF 10% 50V X7R #0402 | YAGEO | CC0402KRX7R9BB272 | C20 | IR board
CAP CC 390pF 5% 50V NPO #0402 | YAGEO | CC0402JRNPO9BN391 | C13 | IR board
CAP CK 47uF ±20% 10V X5R #1206 LMK316ABJ476ML-T TAIYO YUDEN | TAIYO YUDEN | LMK316ABJ476ML-T | C11,C15,C16,C21,C22 | IR board
CAP CS 470uF 20% 4V D3L 4TPE470ML "PANASONIC" | Panasonic | 4TPE470ML | C33,C6 | IR board
CAP CC 4.7uF 10% 10V X5R CHIP #0402 | YAGEO | CC0402KRX5R6BB475 | C29,C32 | IR board
CAP CC 56pF 5% 50V NPO CHIP 0402 | YAGEO | CC0402JRNPO9BN560 | C23 | IR board
INDUCTOR 2.2uH 20% 14A MMD-06CZ-2R2M-V1 SMD "MAGLAYERS" | 美磊 | MMD-06CZ-2R2M-V1 | L1 | IR board
DIODE SCHOTTKY 30V 1A SDM20U30LP-7 DFN1006-2 "DIODES" | Diodes | SDM20U30LP-7 | D1 | IR board
CNNT MINI BRIDGE 4.3A M 4P 1.27mm R/A SMD 214012 "ERNI" | ERNI | 214012 | P5 | IR board
CNNT FPC F 20P 0.5mm RA/SMT 51652-0200N-001 "ACES" | 宏致 | 51652-0200N-001 | P1 | IR board
CNNT FPC M 40P 0.4mm ST/SMT HEIGHT=0.7m WP7B-P040VA1-R6000 "JAE" | JAE | WP7B-P040VA1-R6000 | P2 | IR board
IC STP16CPC26XTR LOW VOLTAGE 16-bit CONSTANT CURRENT LED SINK DRIVER HTSSOP24-EPAD "ST" | ST | STP16CPC26XTR | U4,U5 | IR board
IC TPS54478RTER 2.95-V to 6-V INPUT, 4-A OUTPUT, 2-MHz, SYNCHRONOUS STEP-DOWN WQFN16 "TI" | TI | TPS54478RTER | U1 | IR board
IC TPS7A3701DRVR 1% HIGH-ACCURACY 1A LOW DROPOUT REGULATOR SON6 "TI" | TI | TPS7A3701DRVR | U2 | IR board
IC VSOP58438 PREAMPLIFIER CIRCUIT FOR IR REMOTE CONTROL VSOP8 "VISHAY" | Vishay | VSOP58438 | U7 | IR board
IC STM8S003K3T6C VALUE LINE 16 MHz 8-bit MCU LQFP32 "ST" | ST | STM8S003K3T6CTR | U6 | IR board
PCB BARE PCB L:2 IR BACK BD 1.0mm FR4 EILEEN | EXPRESS | 2058I666B0 | NA | IR back modul
RES RP 0 1% 1/16W CHIP #0402 | Ralec | RTT02000FTH | R401,R404 | IR back modul
CNNT PIN M 10P 0.8mm RA/SMT 50208-01001-001 "ACES" | 宏致 | 50208-01001-001 | P100 | IR back modul
INFRARED EMITTER HIRC3528Q19-B20 850nm "CT-MICRO" | CT-Micro | HIRC3528Q19-B20 | LED2,LED3,LED5,LED6 | IR back modul
CABLE FPC FRONT COVER FOR Eileen HDK 2.0 | 圓裕 | CX-D131B | NA | Front cover
RES RP 330 1% 1/10W CHIP #0402 | UniOhm | HP02WAF3300TCE | R300,R301,R302 | Front cover
CAP CK 10uF ±20% 10V X5R #0603 LMK107BBJ106MALT TAIYO YUDEN | TAIYO YUDEN | LMK107BBJ106MALT | C301 | Front cover
CAP CC 22pF 5% 50V NPO CHIP #0402 | YAGEO | CC0402JRNPO9BN220 | C306 | Front cover
CAP CK 47uF ±20% 10V X5R #1206 LMK316ABJ476ML-T TAIYO YUDEN | TAIYO YUDEN | LMK316ABJ476ML-T | C302,C304 | Front cover
CNNT FPC 11P P=0.5 mm JS-1191PSDR-11G | 喬訊 | JS-1191PSDR-11G | J101 | Front cover
IC STP16CPC26XTR LOW VOLTAGE 16-bit CONSTANT CURRENT LED SINK DRIVER HTSSOP24-EPAD "ST" | ST | STP16CPC26XTR | U300,U301,U302 | Front cover
INFRARED EMITTER HIRC3528Q19-B20 850nm "CT-MICRO" | CT-Micro | HIRC3528Q19-B20 | LED17,LED21,LED22,LED23,LED24,LED25,LED26,LED27,LED28,LED29,LED30,LED32,LED35,LED36,LED37,LED38,LED39,LED40 | Front cover
PHOTO DIODE BPW 34 S 850nm OSRAM OSTAR | OSRAM | BPW 34 S | LED41 | Front cover
CABLE FPC U BOARD FOR Eileen HDK 2.0 | 圓裕 | CX-D132B | NA | U board
CNNT FPC 11P P=0.5 mm JS-1191PSDR-11G | 喬訊 | JS-1191PSDR-11G | J101 | U board
CNNT FPC F 40P 0.4mm ST/SMT HEIGHT=0.7m WP7B-S040VA1-R6000 "JAE" | JAE | WP7B-S040VA1-R6000 | P200 | U board
INFRARED EMITTER HIRC3528Q19-B20 850nm "CT-MICRO" | CT-Micro | HIRC3528Q19-B20 | LED10,LED11,LED12,LED13,LED14,LED15,LED16,LED7,LED8,LED9 | U board

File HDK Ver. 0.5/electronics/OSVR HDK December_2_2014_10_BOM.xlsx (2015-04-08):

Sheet: HDMI_T14I_S_December_2_2014
OSVR Hackers Dev. Kit V. 0.5
HDMI Head Mount Display Revised: Tuesday, December 2, 2014
 |  |  |  | Single HDMI REV-B BOM
Bill Of Materials December 2, 2014 10:45
Item | Quantity | Reference | Part | PCB_Footprint | Mfg | Mfg_Part# | Specifications | Vendor | Vendor Part#
1 | 2 | C1,C3 | 22uF | CC1206-18 | TDK | C3216X5R1V226M160AC | CAP CER 22uF 35V X5R 1206 | Digikey | 445-8045-2-ND
2 | 17 | C2,C28,C100,C101,C145,C175,C220,C455,C470,C496,C504,C602,C606,C630,C632,C639,C640 | 0.1uF | CC0603_IPC7351 | Murata | GRM188R71H104KA93D | CAP CER 0.1UF 50V 10% X7R 0603 | Digikey | 490-1519-1-ND
3 | 127 | C5,C9,C10,C18,C20,C33,C54,C59,C60,C63,C65,C72,C76,C84,C88,C90,C96,C106,C118,C119,C121,C125,C126,C127,C128,C151,C156,C159,C163,C168,C169,C170,C173,C180,C193,C197,C201,C203,C205,C208,C210,C222,C229,C230,C231,C232,C233,C237,C246,C260,C262,C265,C266,C267,C281,C282,C285,C295,C303,C306,C307,C312,C317,C322,C323,C325,C334,C338,C342,C355,C402,C434,C444,C451,C459,C463,C468,C471,C480,C483,C492,C497,C527,C531,C533,C541,C551,C556,C558,C561,C562,C564,C565,C568,C569,C570,C573,C574,C575,C579,C580,C584,C592,C596,C598,C600,C604,C605,C609,C610,C612,C614,C615,C616,C617,C618,C619,C620,C621,C622,C623,C625,C626,C627,C628,C633,C636 | 100nF | CC0402_IPC7351 | TDK | C1005X5R1E104K | CAP CER .10UF 25V X5R 0402 | Digikey | 445-4964-1-ND
4 | 20 | C6,C26,C34,C38,C41,C43,C45,C48,C81,C104,C105,C108,C109,C129,C130,C161,C174,C576,C577,C601 | 47uF 10V | CC1206-18 | TDK | C3216X5R1A476M | CAP CER 47UF 10V X5R 20% 1206 | Digikey | 445-6006-1-ND
5 | 4 | C19,C67,C123,C124 | 390pF | CC0402_IPC7351 | Murata | GRM155R71H391KA01D | CAP CER 390PF 50V 10% X7R 0402 | Digikey | 490-3249-1-ND
6 | 1 | C23 | 56pF | CC0402_IPC7351 | KEMET | C0402C560K5GACTU | CAP 0402 56pF 50volts C0G 10% | MOUSER | 80-C0402C560K5G
7 | 5 | C24,C187,C247,C269,C324 | 1uF | CC0402_IPC7351 | Murata | GRM155R61A105KE15D | CAP CER 1UF 10V X5R 0402 | Digikey | 490-3890-2-ND
8 | 1 | C25 | 2.7nF | CC0402_IPC7351 | Vishay | VJ0402Y272KNAAJ | CAP CER 2.7nF 50V X7R 0402 | Digikey | 720-1215-2-ND
9 | 7 | C27,C30,C31,C32,C110,C114,C588 | 18pF | CC0402_IPC7351 | Murata | GJM1555C1H180JB01D | CAP CER 18PF 50V 5% NP0 0402 | Digikey | 490-3119-1-ND
10 | 8 | C29,C36,C49,C51,C111,C112,C113,C115 | 47uF | CC0805_IPC7351 | Taiyo Yuden | JMK212BJ476MG-T | Ceramic, 47uF, 0805, 6.3V, 20%, X5R | Digikey | 587-1779-6-ND
11 | 1 | C39 | 100nF | CC0402_IPC7351 | TDK | C1005X5R1E104K | CAP CER 0.1UF 25V 10% X5R 0402 | Digikey | 445-4964-1-ND
12 | 1 | C42 | 10uF | CASE-A-3216 | KEMET | T494A106M010AT | CAP TANT 10UF 10V 20% 1206 Case-A | Digikey | 399-8432-1-ND
13 | 25 | C52,C73,C78,C79,C85,C86,C89,C107,C165,C167,C240,C255,C297,C390,C400,C435,C535,C624,C629,C634,C635,C641,C642,C643,C644 | 10uF | CC0603_IPC7351 | Taiyo Yuden | LMK107BJ106MALTD | CAP CER 10UF 10V X5R 20% 0603 | Digikey | 587-2562-2-ND
14 | 1 | C57 | 4.7nF | CC0402_IPC7351 | Murata | GRM155R71H472KA01J | CAP CER 4700PF 50V 10% X7R 0402 | Mouser | 81-GRM155R71H472KA1J
15 | 3 | C61,C120,C122 | 33pF | CC0402_IPC7351 | Yageo | CC0402JRNPO9BN330 | CAP CER 33PF 50V 5% NPO 0402 | Digikey | 311-1020-1-ND
16 | 1 | C74 | 82pF | CC0402_IPC7351 | TDK | C1005C0G1H820J050BA | CAP CER 82pF 0402 50V 5% C0G | Digikey | 445-1246-1-ND
17 | 2 | C75,C398 | 22uF 6.3V | CC0805_IPC7351 | Murata | GRM21BR60J226ME39L | CAP CER 22UF 6.3V 20% X5R 0805 | Digikey | 490-1719-1-ND
19 | 5 | C83,C157,C298,C545,C548 | 15nF | CC0402_IPC7351 | Kemet | C0402C153K8PACTU | CAP 15000PF 10V CERAMIC X5R 0402 | Digikey | 399-3011-1-ND
20 | 2 | C87,C99 | 10pF | CC0402_IPC7351 | Samsung | CL05C100JB5NNNC | CAP CER 10PF 50V 5% NP0 0402 | Digikey | 1276-1139-1-ND
21 | 5 | C94,C95,C587,C594,C595 | 4.7uF | CC0805 | Taiyo-Yuden | TMK212AB7475KG-T | CAP CER 4.7UF 25V 10% X7R 0805 | Digikey | 587-2990-1-ND
22 | 3 | C97,C103,C597 | 1nF | CC0402_IPC7351 | Kemet | C0402C102K5RACTU | CAP 1000PF 50V CERAMIC X7R 0402 | Digikey | 399-1032-1-ND
23 | 1 | C116 | 8.2nF | CC0402_IPC7351 | Kemet | C0402C822K4RACTU | CAP CER 8200PF 16V X7R 0402 | Digikey | 399-1037-1-ND
24 | 1 | C117 | 2.2nF | CC0402_IPC7351 | TDK | C1005X7R1H222K050BA | CAP 2.2nF 0402 X7R 50V 10% | Digikey | 445-1257-1-ND
25 | 1 | C136 | 470pF | CC0603_IPC7351 | Murata | GRM1885C1H471JA01D | CAP CER 470PF 50V 5% NP0 0603 | Digikey | 490-1443-1-ND
26 | 9 | C144,C153,C164,C189,C209,C212,C244,C581,C603 | 10nF | CC0402_IPC7351 | Murata | GRM155R71H103KA88D | CAP CER 10000PF 50V 10% X7R 0402 | Digikey | 490-4516-1-ND
27 | 80 | C176,C179,C183,C191,C200,C204,C207,C214,C215,C217,C228,C234,C239,C249,C250,C254,C258,C271,C275,C280,C289,C292,C301,C302,C308,C310,C316,C320,C321,C326,C327,C329,C341,C345,C347,C349,C356,C361,C362,C367,C374,C379,C388,C399,C403,C406,C417,C425,C426,C427,C428,C430,C431,C438,C439,C440,C447,C449,C452,C454,C461,C473,C479,C488,C499,C510,C516,C519,C520,C523,C524,C528,C530,C537,C538,C544,C547,C549,C559,C566 | 100nF | CC0201_IPC7351_EINF4398 | TDK | C0603X5R1A104K030BC | CAP CER .10UF 10V X5R 0201 | Digikey | 445-7318-1-ND
28 | 6 | C195,C458,C491,C517,C586,C631 | 33uF | CC0805_IPC7351 | TDK Corporation | C2012X5R0J336M125AC | CAP CER 33UF 6.3V X5R 20% 0805 | Digikey | 445-5986-1-ND
30 | 20 | C309,C336,C346,C366,C375,C383,C384,C389,C395,C404,C416,C419,C420,C424,C437,C441,C457,C467,C485,C494 | 10nF | CC0201_IPC7351_EINF4398 | Murata | GRM033R71A103KA01D | CAP CERAMIC .01UF 10V X7R 0201 | Digikey | 490-3194-1-ND
31 | 1 | C396 | 10nF | CC0402_IPC7351 | Murata | GRM155R71H103KA88D | CAP CER 10000PF 50V X7R 0402 | Digikey | 490-4516-1-ND
32 | 1 | C578 | 220pF | CC0402_IPC7351 | Murata | GRM1555C1H221JA01D | CAP CER 220PF 50V 5% C0G 0402 | Digikey | 490-1293-1-ND
33 | 2 | C589,C638 | 1uF | CC0603_IPC7351 | Murata | GRM188R61A105KA61D | CAP CER 1UF 10V 10% X5R 0603 | Digikey | 490-1543-1-ND
34 | 1 | C590 | 1.2nF | CC0402_IPC7351 | Yageo | CC0402KRX7R9BB122 | CAP CER 1200PF 50V 10% X7R 0402 | Digikey | 311-1031-1-ND
35 | 2 | C591,C593 | 22uF | CC0805_IPC7351 | Samsung | CL21A226MPQNNNE | CAP CER 22UF 10V 20% X5R 0805 | Digikey | 1276-2910-1-ND
36 | 1 | C599 | 1uF | CC0603_IPC7351 | Taiyo Yuden | UMK107BJ105KA-T | CAP CER 1UF 50V 10% X5R 0603 | Digikey | 587-2400-1-ND
37 | 2 | C611,C613 | 22pF | CC0402_IPC7351 | Murata | GRM1555C1H220JZ01D | CAP CER 22PF 50V 5% C0G 0402 | Digikey | 490-1283-2-ND
39 | 1 | D1 | SMBJ6V0CA | D-SMB | Fairchild | SMBJ6V0CA | TVS BIDIRECT 600W 6V SMB | Digikey | SMBJ6V0CACT-ND
40 | 1 | D4 | MBR0540 | SOD-123 | Fairchild | MBR0540 | DIODE SCHOTTKY 40V 0.5A SOD123 | DigiKey | MBR0540CT-ND
41 | 1 | D6 | MMSZ5227BT1G | SOD-123 | On Semiconductor | MMSZ5227BT1G | DIODE ZENER 3.6V 500MW SOD123 | Digikey | MMSZ5227BT1GOSCT-ND
42 | 1 | D7 | 1N4148WS | SOD-323F | FAIRCHILD | 1N4148WS | DIODE SML SIG 75V 0.15A SOD323F | Digikey | 1N4148WSFSCT-ND
43 | 1 | D8 | MBR0520LCT-ND | SOD123 | Fairchild-Semi | MBR0520L | DIODE SCHOTTKY 20V 0.5A SOD123 | Digikey | MBR0520LCT-ND
44 | 1 | D9 | MM3Z15VC | SOD323F | Fairchild Semiconductor | MM3Z15VC | DIODE ZENER 15V 200MW SOD323F | Digikey | MM3Z15VCDKR-ND
45 | 7 | ESD5,ESD6,ESD8,ESD10,ESD11,ESD15,ESD18 | PGB1010603MR | SUP_PGB1010603MR | Littelfuse Inc | PGB1010603MR | SUPPRESSOR ESD 24VDC 0603 SMD | Digikey | F2594CT-ND
46 | 3 | ESD12,ESD13,ESD14 | DIODE DIAC | DIO_RCLAMP0521P | SEMTECH | RClamp0521P.TCT | SUPPRESSOR ESD 6VDC 0402 SMD | Digikey | RCLAMP0521PTR-ND
48 | 6 | FB1,FB2,FB56,FB57,FB59,FB61 | FERRITE BEAD | FB1206 | Steward | HI1206T161R-10 | FERRITE CHIP POWER 160 OHM SMD | Digikey | 240-2411-1-ND
49 | 12 | FB4,FB8,FB10,FB23,FB24,FB26,FB31,FB36,FB37,FB38,FB44,FB62 | 100R | FB0402 | WURTH | 742792731 | FERRITE BEAD 100 OHM 1.2A 0402 | Digikey | 732-2362-1-ND
51 | 4 | FB6,FB7,FB14,FB16 | 80R | INDC0805 | Laird | HI0805R800R-10 | FERRITE CHIP POWER 80 OHM SMD | Digikey | 240-2395-1-ND
52 | 11 | FB9,FB11,FB13,FB17,FB41,FB48,FB50,FB51,FB53,FB55,FB58 | 100R | FB0603 | TDK | MPZ1608S101A | FERRITE CHIP 100 OHM 3A 0603 | Digikey | 445-1564-1-ND
55 | 1 | FS1 | MF-LSMF300/24X, I_Hold=3A | MF-LSMF300_24X | Bourns | MF-LSMF300X-2 | FUSE PTC RESET 3.0A 6V SMD | DIGIKEY | MF-LSMF300X-2CT-ND
58 | 1 | J6 | CON10A | M50-3600542 | HARWIN | M50-3600542 | CONN HDR 1.27MM SMD AU 10POS | Digikey | 952-1389-ND
59 | 1 | J10 | 530470510 | 53047-0510 | MOLEX | 53047-0510 | CONN HEADER 5POS 1.25MM VERT TIN | Digikey | WM1734-ND
61 | 1 | J16 | FH12-36S-0.5SH(55) | FH12-36S-0_5SH | Hirose | FH12-36S-0.5SH(55) | CONN FPC/FFC 36POS .5MM HORZ SMD | Digikey | HFJ136CT-ND
62 | 1 | J18 | WM1731-ND | 053047-0210 | MOLEX | 530470210 |  | Digikey
63 | 1 | J19 | 877591015 | 0877591015_A3A-10PA | MOLEX | 877591015 | CONN HEADER 14POS 2MM VERT SMD | Digikey | WM3589-ND
64 | 1 | J21 | USB 3.0 Type A | 2UB2311-000111F | SINGATRON | 2UB2311-000111F
65 | 1 | J22 | TFM-107-02-L-DH | TFM-107-02-L-DH | TFM-107-02-L-DH | TFM-107-02-L-DH
66 | 12 | LD2,LD3,LD4,LD5,LD6,LD7,LD8,LD11,LD12,LD13,LD14,LD15 | LED, GRN | LED_SML-LX0603GW | Lumex | SML-LX0603GW-TR | LED 565NM GRN DIFF 0603 SMD | Digikey | 67-1549-1-ND
69 | 2 | L5,L9 | 5.6uH,103mOhm,3A | IND_IHLP2020CZ | VISHAY | IHLP2020BZER5R6M11 | POWER INDUCTOR 5.6UH 3A SMD | DIGKEY | 541-1223-1-ND
71 | 1 | L11 | 33uH | IND_VLF5014ST | TDK Corporation | VLF5014AT-330MR50 | INDUCTOR POWER 33UH .5A SMD | Digikey | 445-4196-2-ND
72 | 1 | L13 | 4.7uH,77mOhm,3.5A | IND_IHLP2020CZ | VISHAY | IHLP2020CZER4R7M11 | INDUCTOR POWER 4.7UH 4.5A SMD | DIGKEY | 541-1238-2-ND
73 | 1 | L14 | 3.3uH,40mOhm,5.5A | IND_IHLP2020CZ | VISHAY | IHLP2020CZER3R3M11 | POWER INDUCTOR 3.3UH 5.5A SMD | DIGKEY | 541-1237-1-ND
74 | 1 | L16 | 2.2uH | NR3015 | Taiyo Yuden | NR3015T2R2M | INDUCTOR 2.2UH 20% SMD | Digikey | 587-1648-1-ND
75 | 2 | L18,L19 | 22uH | 744028220 | WE | 744028220 | INDUCTOR POWER 22UH .4A SMD | Digikey | 732-2200-1-ND
76 | 2 | L21,L22 | DLP11SA900HL2L | IND_DLP11S | Murata | DLP11SA900HL2L | CHOKE COMMON MODE 90 OHM SMD | Digikey | 490-6035-1-ND
78 | 1 | OSC1 | 27MHz | XTAL_ASEK | Abracon Corporation | ASE-27.000MHZ-LC-T | OSCILLATOR 27.000 MHZ 3.3V SMD | Digikey | 535-9569-1-ND
79 | 2 | Q4,Q16 | NTJD1155LT1G | SOT363_6 | ON Semiconductor | NTJD1155LT1G | MOSFET N/P-CH 8V 1.3A SOT-363 | Digikey | NTJD1155LT1GOSTR-ND
80 | 1 | Q6 | FDY3000NZ | SC89_6P | Fairchild Semiconductor | FDY3000NZ | MOSFET N-CH DUAL SC89 | Digikey | FDY3000NZTR-ND
81 | 5 | Q7,Q11,Q12,Q15,Q18 | MMBT2222LT1G | SOT23 | OnSemi | MMBT2222LT1G | TRANS GP SS NPN 30V SOT23 | Digikey | MMBT2222LT1GOSCT-ND
82 | 3 | Q10,Q14,Q17 | 2N7002-7-F | SOT23_132 | Diodes Inc | 2N7002-7-F | N-Chanel MOSFET, 60V, 115mA, SOT-23 | Digikey | 2N7002-FDICT-ND
83 | 2 | Q19,Q20 | SIS434DN-T1-GE3 | PWR-PAK_1212_EINF4399 | Vishay/Siliconix | SIS434DN-T1-GE3 | N-CHANNEL 40-V (D-S) MOSFET | Digikey | SIS434DN-T1-GE3CT-ND
84 | 13 | RN1,RN2,RN6,RN8,RN11,RN13,RN14,RN15,RN16,RN17,RN19,RN21,RN23 | RPack4-33 | RESN_EXB28V_0402X4 | Panasonic - ECG | EXB-28V330JX | RES ARRAY 33 OHM 5% 4 RES SMD | Digikey | Y7330CT-ND
85 | 10 | RN28,RN29,RN30,RN31,RN33,RN39,RN41,RN43,RN45,RN46 | RPack4-47 | RESN_EXB28V_0402X4 | Panasonic - ECG | EXB-28V470JX | RES ARRAY 47 OHM 5% 4 RES SMD | Digikey | Y7470CT-ND
86 | 53 | R19,R30,R38,R72,R81,R89,R106,R108,R118,R126,R127,R132,R136,R137,R138,R140,R142,R145,R146,R153,R177,R184,R199,R201,R207,R211,R212,R265,R266,R267,R268,R309,R318,R369,R422,R486,R488,R489,R493,R500,R505,R524,R526,R527,R528,R538,R542,R543,R544,R545,R558,R289,R294 | 10K | RC0402_IPC7351 | Panasonic - ECG | ERJ-2RKF1002X | RES 10.0K OHM 1/10W 1% 0402 SMD | Digikey | P10.0KLCT-ND
87 | 71 | R25,R34,R42,R48,R62,R66,R67,R75,R83,R85,R86,R107,R112,R113,R144,R159,R162,R164,R165,R166,R168,R169,R171,R172,R174,R176,R178,R180,R182,R202,R203,R226,R235,R237,R241,R242,R243,R244,R245,R256,R259,R271,R308,R311,R351,R392,R404,R427,R430,R436,R468,R469,R473,R475,R476,R479,R480,R501,R516,R517,R518,R519,R539,R540,R548,R549,R553,R554,R562,R563,R336 | 0R | RC0402_IPC7351 | Panasonic - ECG | ERJ-2GE0R00X | RES 0.0 OHM 1/10W 0402 SMD | Digikey | P0.0JCT-ND
88 | 17 | R27,R55,R117,R224,R250,R252,R340,R354,R396,R409,R440,R464,R478,R499,R502,R529,R491 | 1K | RC0402_IPC7351 | Panasonic-ECG | ERJ-2RKF1001X | RES 1.00K OHM 1/10W 1% 0402 SMD | Digikey | P1.00KLTR-ND
89 | 1 | R28 | 45.3K | RC0402_IPC7351 | Panasonic | ERJ-2RKF4532X | RES 45.3K OHM 1/10W 1% 0402 SMD | DIGKEY | P45.3KLCT-ND
90 | 1 | R37 | 20.5 K | RC0402_IPC7351 | Panasonic | ERJ-2RKF2052X | RES 20.5K OHM 1/10W 1% 0402 SMD | DIGKEY | P20.5KLCT-ND
91 | 4 | R41,R84,R186,R187 | 78.7K | RC0402_IPC7351 | Vishay-Dale | CRCW040278K7FKED | RES 78.7K OHM 1/16W 1% 0402 SMD | DIGKEY | 541-78.7KLCT-ND
92 | 17 | R46,R49,R90,R100,R102,R105,R115,R304,R380,R400,R405,R408,R410,R412,R417,R420,R425 | 33R | RC0402_IPC7351 | Panasonic - ECG | ERJ-2RKF33R0X | RES 33.0 OHM 1/10W 1% 0402 SMD | Digikey | P33.0LCT-ND
93 | 2 | R52,R398 | 330R | RC0402_IPC7351 | Panasonic - ECG | ERJ-2RKF3300X | RES 330 OHM 1/10W 1% 0402 SMD | Digikey | P330LCT-ND
94 | 7 | R53,R64,R175,R188,R239,R525,R561 | 1M | RC0402_IPC7351 | Panasonic | ERJ-2RKF1004X | RES 1M OHM 1/16W 1% 0402 SMD | Digikey | P1.00MLCT-ND
95 | 14 | R63,R125,R316,R321,R326,R334,R342,R343,R395,R443,R447,R450,R503,R504 | 49.9R | RC0402_IPC7351 | Panasonic - ECG | ERJ-2RKF49R9X | RES 49.9 OHM 1/10W 1% 0402 SMD | Digikey | P49.9LCT-ND
96 | 2 | R69,R523 | 12K | RC0402_IPC7351 | Panasonic - ECG | ERJ-2RKF1202X | RES 12K OHM 1/10W 1% 0402 SMD | Digikey | P12.0KLCT-ND
99 | 40 | R87,R92,R94,R95,R96,R204,R227,R228,R229,R230,R234,R253,R276,R285,R288,R302,R307,R319,R328,R329,R332,R341,R348,R349,R352,R353,R355,R374,R381,R385,R389,R419,R431,R454,R461,R466,R467,R472,R497,R511 | 4.7K | RC0402_IPC7351 | Panasonic-ECG | ERJ-2RKF4701X | RES 4.7K OHM 1/10W 1% 0402 SMD | Digikey | P4.70KLCT-ND
101 | 1 | R91 | 13K | RC0402_IPC7351 | Panasonic - ECG | ERJ-2RKF1302X | RES 13.0K OHM 1/10W 1% 0402 SMD | DIGKEY | P13.0KLCT-ND
102 | 1 | R122 | 20K | RC0402_IPC7351 | Panasonic | ERJ-2RKF2002X | RES 20.0K OHM 1/10W 1% 0402 SMD | DIGKEY | ERJ-2RKF2002X
103 | 1 | R128 | 133K | RC0402_IPC7351 | Panasonic - ECG | ERJ-2RKF1333X | RES 133K OHM 1/10W 1% 0402 SMD | Digikey | P133KLCT-ND
104 | 9 | R131,R219,R222,R247,R323,R453,R495,R498,R506 | 49.9K | RC0402_IPC7351 | Panasonic - ECG | ERJ-2RKF4992X | RES 49.9K OHM 1/10W 1% 0402 SMD | Digikey | P49.9KLTR-ND
105 | 12 | R141,R149,R150,R254,R286,R313,R416,R421,R492,R514,R515,R522 | 100K | RC0402_IPC7351 | Panasonic - ECG | ERJ-2RKF1003X | RES 100K OHM 1/10W 1% 0402 SMD | Digikey | P100KLTR-ND
107 | 1 | R193 | 8.25K | RC0402_IPC7351 | Panasonic - ECG | ERJ-2RKF8251X | RES 8.25K OHM 1/10W 1% 0402 SMD | DIGKEY | P8.25KLCT-ND
108 | 3 | R194,R200,R446 | 51K | RC0402_IPC7351 | Panasonic - ECG | ERJ-2GEJ513X | RES 51K OHM 1/10W 5% 0402 SMD | Digikey | P51KJTR-ND
109 | 1 | R195 | 11.3 K | RC0402_IPC7351 | Vishay-Dale | CRCW040211K3FKED | RES 11.3K OHM 1/16W 1% 0402 SMD | DIGKEY | 541-11.3KLTR-ND
111 | 2 | R208,R496 | 15K | RC0402_IPC7351 | Panasonic - ECG | ERJ-2RKF1502X | RES 15.0K OHM 1/10W 1% 0402 SMD | Digikey | P15.0KLCT-ND
112 | 2 | R220,R509 | 4.7K | RC0603 | Panasonic | ERJ-3EKF4701V | RES 4.7K OHM 1/10W 1% 0603 SMD | Digikey | P4.70KHCT-ND
113 | 2 | R248,R274 | 220K | RC0603_IPC7351 | Panasonic - ECG | ERJ-3EKF2203V | RES 220K OHM 1/10W 1% 0603 SMD | DIGIKEY | P220KHCT-ND
114 | 12 | R255,R278,R303,R320,R327,R373,R401,R438,R449,R474,R477,R536 | 100R | RC0402_IPC7351 | Panasonic - ECG | ERJ-2GEJ101X | RES 100 OHM 1/10W 1% 0402 SMD | Digikey | P100LCT-ND
115 | 2 | R306,R428 | 240R | RC0402_IPC7351 | Panasonic-ECG | ERJ-2RKF2400X | RES 240 OHM 1/10W 1% 0402 SMD | Digikey | P240LCT-ND
117 | 2 | R394,R455 | 220R | RC0402_IPC7351 | Panasonic - ECG | ERJ-2GEJ221X | RES 220 OHM 1/10W 5% 0402 SMD | Digikey | P220JCT-ND
118 | 1 | R463 | 2.21K | RC0402_IPC7351 | Panasonic-ECG | ERJ-2RKF2211X | RES 2.21K OHM 1/10W 1% 0402 SMD | Digikey | P2.21KLCT-ND
119 | 2 | R465,R547 | 47K | RC0402_IPC7351 | Panasonic - ECG | ERJ-2GEJ473X | RES 47K OHM 1/10W 5% 0402 SMD | Digikey | P47KJTR-ND
121 | 1 | R483 | 487K | RC0402_IPC7351 | Panasonic - ECG | ERJ-2RKF4873X | RES 487K OHM 1/10W 1% 0402 SMD | Digikey | P487KLCT-ND
122 | 1 | R484 | 48.7K | RC0402_IPC7351 | Panasonic - ECG | ERJ-2RKF4872X | RES 48.7K OHM 1/10W 1% 0402 SMD | Digikey | P48.7KLCT-ND
123 | 1 | R485 | 32.4K | RC0402_IPC7351 | Panasonic - ECG | ERJ-2RKF3242X | RES 32.4K OHM 1/10W 1% 0402 SMD | Digikey | P32.4KLCT-ND
124 | 2 | R507,R508 | 4.7R | RC0603 | Panasonic-ECG | ERJ-3RQF4R7V | RES 4.7 OHM 1/10W 1% 0603 SMD | Digikey | P4.7AJCT-ND
125 | 2 | R510,R560 | 2.1M | RC0402_IPC7351 | VISHAY | CRCW04022M10FKED | RES 2.10M OHM 1/16W 1% 0402 SMD | Digikey | 541-2.10MLCT-ND
126 | 1 | R512 | 86.6K | RC0402_IPC7351 | Panasonic | ERJ-2RKF8662X | RES 86.6K OHM 1/10W 1% 0402 SMD | Digikey | P86.6KLCT-ND
127 | 1 | R513 | 210K | RC0402_IPC7351 | Panasonic - ECG | ERJ-2RKF2103X | RES 210K OHM 1/10W 1% 0402 SMD | Digikey | P210KLCT-ND
128 | 1 | R551 | 100R | RC0603 | Panasonic | ERJ-3EKF1000V | RES 100 OHM 1/10W 1% 0603 SMD | Digikey | P100HCT-ND
129 | 2 | R556,R557 | 1.69K | RC0402_IPC7351 | Panasonic-ECG | ERJ-2RKF1691X | RES 1.69K OHM 1/10W 1% 0402 SMD | Digikey | P1.69KLCT-ND
130 | 2 | SW1,SW2 | B3U-1000P-B | B3U-1000P-B | Omron | B3U-1000P-B | SWITCH TACTILE SPST-NO 0.05A 12V | Digikey | SW1143CT-ND
135 | 4 | U4,U16,U29,U30 | TPS54478RTET | QFN50P300X300_16_PWP_TI_EINF_1 | Texas Instruments | TPS54478RTET | IC CONV STP-DN SYNC ADJ 16WQFN | Digikey | 296-29064-1-ND
136 | 2 | U6,U8 | RCLAMP0524P.TCT | CAPN_RCLAMP0524 | Semtec | RCLAMP0524P.TCT | TVS ARRAY SLP2510P8 10-PIN | Digikey | RCLAMP0524PCT-ND
137 | 1 | U7 | MIC8114TUY | SOT-143 | Micrel | MIC8114TUY TR | IC SUPERVISOR RESET 3.08V SOT143 | Digikey | 576-1322-1-ND
138 | 1 | U10 | TDA19971BHN/C1 | HVQFN72 | NXP | TDA19971BHN/C1 | IC HDMI RECEIVER SGL 72HVQFN | Digikey | TDA19971BHN/C1,557-ND
139 | 2 | U11,U28 | MT41J64M16JT-15E IT:G TR | FBGA80P_8X14_96_EINF_1 | Micron | MT41J64M16JT-15E IT:G TR | IC DDR3 SDRAM 1GBIT 667MHZ 96BGA | DIGIKEY | 557-1497-1-ND
140 | 1 | U12 | ATXMEGA256A3BU-MHR | QFN-64M2 | ATMEL | ATXMEGA256A3BU-MHR | IC MCU 8BIT 256KB FLASH 64QFN | Digikey | ATXMEGA256A3BU-MHRCT-ND
141 | 1 | U19 | TPS61170DRVR | SON65P200X200_6_PWP_EINF4398 | Texas Instruments | TPS61170DRV | IC BOOST REGULATOR 38V 6-SON | Digikey | 296-22945-1-ND
142 | 1 | U20 | FXO-LC736R-200 | OSC_FXO-LC736R-200P00 | FOX | FXO-LC736R-200 | OSC 200.000 MHZ LVDS MEMS SMD | Digikey | 631-1362-1-ND
143 | 1 | U23 | XC6SLX45-3CSG484C | FPBGA80P_19X19_484_EINF4401 | Xilinx | XC6SLX45-3CSG484C | IC FPGA SPARTAN 6 43K 484CSGBGA | Digikey | 122-1736-ND
144 | 1 | U24 | SSD2828QN4 | 68-QFN-EP | SOLOMON SYSTECH | SSD2828QN4 | MIPI Master Bridge | ANY | Not Available
145 | 1 | U25 | TPS51200DRCR | SON50P300X300_10_PWP | TI | TPS51200DRCT | IC SINK/SOURCE DDR TERMINATION REGULATOR | Digikey | 296-26978-1-ND
146 | 1 | U31 | TXS0104ERGYR | PVQFN-14 | TI | TXS0104ERGYR | IC,Voltage level translator,VQFN-14_EP | Digikey | 296-20698-1-ND
147 | 1 | U33 | SP1004-04VTG | SOT953 | Littelfuse Inc | SP1004-04VTG | TVS DIODE ARRAY 4CH 8KV SOT953 | Digikey | F3502CT-ND
148 | 1 | U34 | RClamp0502A | SC89_6P | SEMTECH | RClamp0502A.TCT | TVS DIODE 50W 5V 2CH BI SC89-6,add Temperatur :-55°C to 125°C | Digikey | RCLAMP0502ACT-ND
149 | 1 | U35 | NC7SZ08M5X | SOT23-5 | FAIRCHILD | NC7SZ08M5X | IC GATE AND 2-INPUT SGL SOT-23-5 | Digikey | NC7SZ08M5XCT-ND
150 | 1 | U36 | UDA1334BTS | SSOP16 | NXP | UDA1334BTS | Audio D/A Converter ICs ULTRA LOW COST DAC | Mouser | 771-UDA1334BTSDH
151 | 1 | U37 | W25Q32FVZPIG | 8-WSON-ZP-6x5 | WINBOND | W25Q32FVZPIG | IC FLASH 32MBIT 104MHZ 8WSON | Digikey | W25Q32FVZPIG-ND
153 | 1 | U41 | BNO070 | LGA-28 | BOSCH | BNO070
154 | 1 | U42 | RT6150AGQW | WDFN-10L_3x3 | Richtek | RT6150AGQW | IC REG BUCK BST FIX/ADJ 10WDFN | Digikey | 1028-1259-1-ND
155 | 1 | U43 | LT1611CS5_PBF | SOT23_5 | Linear | LT1611CS5#TRMPBF | IC REG INV ADJ 0.3A SOT23-5 | Digikey | LT1611CS5#TRMPBFCT-ND
156 | 1 | U44 | ADCMP371 | SC70-5 | Analog Devices | ADCMP370AKS | IC COMPARATOR PUSH-PULL SC70-5 | Digikey | ADCMP371AKSZ-REEL7CT-ND
157 | 1 | U45 | LTC4365IDDB | 8-LEAD_DFN3X2 | Linear Technology | LTC4365IDDB#TRPBF |  | Digikey | LTC4365IDDB#TRMPBFCT-ND
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

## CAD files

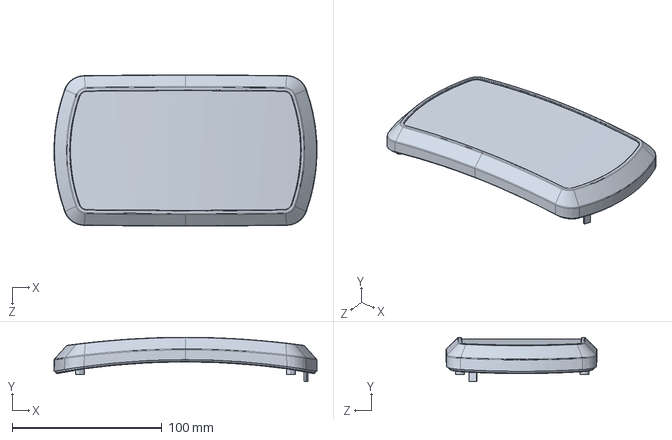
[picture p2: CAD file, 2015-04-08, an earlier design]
_Legacy files/HDK Ver 1.1/mechanical/HOUSING_FRONT_COVER_MB.STEP
175.9 x 29.7 x 101.0 mm

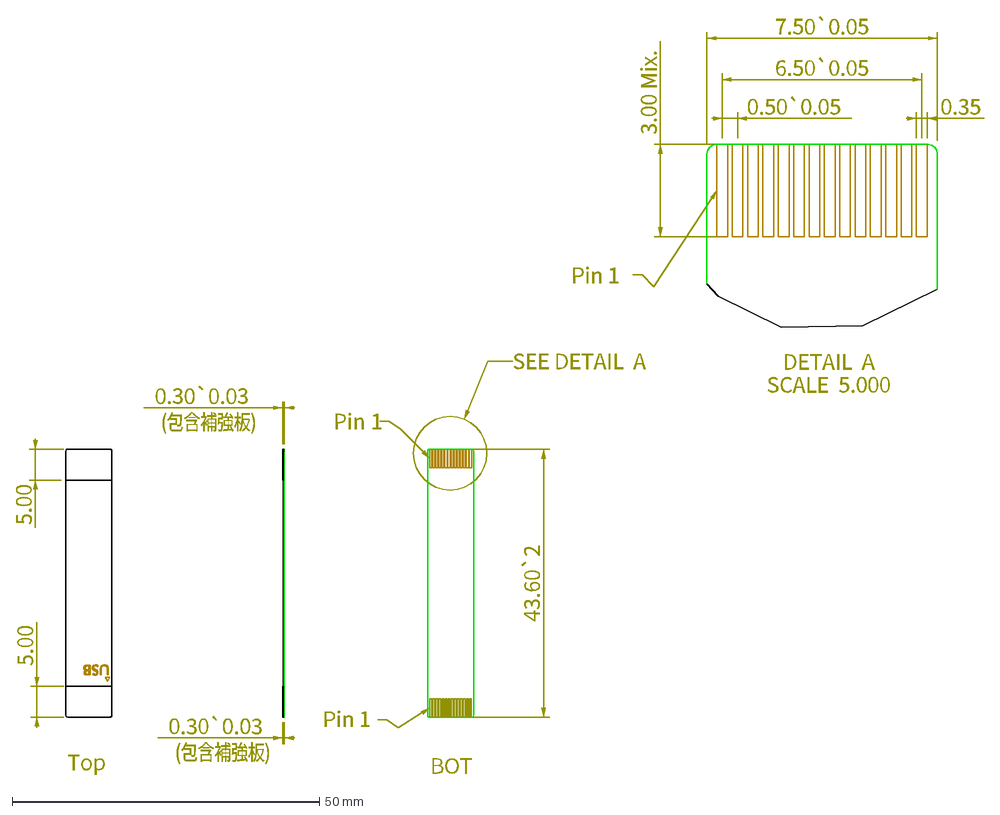
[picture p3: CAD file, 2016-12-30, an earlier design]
HDK Ver 1.1/electronics/usb_fpc-001-all/usb_fpc-001-gbr-all/usb-fpc-001-dxf/usb_to_mb_fpc_cable_1231_v3.dxf
0.35
3.00 Mix.
5.00
Top
BOT
(包含補強板)
SEE DETAIL A
DETAIL A SCALE 5.000
Pin 1
Pin
1

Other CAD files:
HDK Ver 1.2/electricals/gerber/front-cover-dvt2-gbr-all/front-cover-dvt2-dxf/front_cover_led-core-0508-03.dxf
HDK Ver 1.2/electricals/gerber/u-board-dvt-gbr-all/u-board-dvt-dxf/u_board_core-0508.dxf
HDK Ver 1.3/electronics/gerber files/front-cover-dvt2-gbr-all/front-cover-dvt2-dxf/front_cover_led-core-0508-03.dxf
HDK Ver 1.3/electronics/gerber files/u-board-dvt-gbr-all/u-board-dvt-dxf/u_board_core-0508.dxf
HDK Ver 1.1/electronics/belt_box-002-all/belt-box-002-library/bw_wcm2012f2s-900t04.psm
HDK Ver 1.1/electronics/belt_box-002-all/belt-box-002-library/c0402.psm
HDK Ver 1.1/electronics/belt_box-002-all/belt-box-002-library/c0603.psm
HDK Ver 1.1/electronics/belt_box-002-all/belt-box-002-library/c0805.psm
HDK Ver 1.1/electronics/belt_box-002-all/belt-box-002-library/c1206.psm
HDK Ver 1.1/electronics/belt_box-002-all/belt-box-002-library/dlp11t.psm
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

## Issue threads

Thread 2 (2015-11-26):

Sources for MCU binaries?

cyrozap, 2015-11-26:
Will the microcontroller firmware be made open source? It would be nice to have that available so support for other displays could be added.

IvanChen0, 2015-12-22:
the same question!

Oxore, 2016-03-02:
Btw, what about Spartan FPGA RTL firmware? Going to build all hardware by myself and can't find FPGA firmware here.

tovax, 2016-03-22:
The same question!

Kasijjuf, 2016-08-10:
Still waiting for the firmware source. Hurry up and release the firmware source code or stop falsely claiming this project is open source.

bendiken, 2018-01-30:
Did this ever happen?

rpavlik, 2018-07-29:
It's up to Razer to do this now and keep promises, everything from third
parties was approved as far as I know.

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

MulanVR, 2018-07-30:
Ryan, can you make the firmware public? It's in sensics repo. Razer had been also asking (for 2 years now) to make this public...

rpavlik, 2018-08-11:
Sorry about the miscommunications - the asks hadn't made it down to my level, thought there might still be some approval required.

Have now opened the repo: https://github.com/OSVR/OSVR-HDK-MCU-Firmware

ShalokShalom, 2018-11-03:
Is there still any plan to release the hardware also?

godbyk, 2018-11-03:
@ShalokShalom See the https://github.com/OSVR/OSVR-HDK repository.

ShalokShalom, 2018-11-03:
Thanks. Can you help to clear things up? Wikipedia says, this is not really open source:
https://en.wikipedia.org/wiki/Open_Source_Virtual_Reality

justinclift, 2018-11-03:
Interesting question.  Looking at the [License in the GitHub repo](https://github.com/OSVR/OSVR-HDK/blob/master/LICENSE.md), it's clearly **not** Open Source.  Clause 3 includes this:

> ... you may not use, sell or **distribute** the MDK, Modules or Module Interface Technology nor the IPR contained therein for any purposes whatsoever ...

As a data point, clause 8 specifically excludes the source code from that license:

> Any software, namely Source Code or Object Code that is made available on the OSVR Project is excluded from the terms of this License. Such software will be governed by separate terms and conditions set out elsewhere at www.osvr.com.

Not sure what the source code license is, as I didn't see anything obvious when checking the www.osvr.com website quickly.  The license for the non-source-code pieces is very clear though.

MulanVR, 2018-11-03:
Any OSVR partner is allowed to produce and sell derivative work. The limitations are based on aknowledgement of being in fact derivative, and guidance on "powered by OSVR" logo plus marketing messaging if any. The logo guidance is available on the marketing section.
The goal here as always been to strengthen an open and horizontal ecosystem, which by the way it's entirely free and owned by the community, and allow everybody to accelerate their development to go focus on the hard problems of VR without wasting too much time on reinventing the wheel.
Go produce something awesome!

ShalokShalom, 2018-11-04:
> Any OSVR partner is allowed to produce and sell derivative work. The limitations are based on aknowledgement of being in fact derivative, and guidance on "powered by OSVR" logo plus marketing messaging if any. The logo guidance is available on the marketing section.

That would be the case in BSD licences too. Why is OSVR not accepted as an open source license by Github and why is OSVR using an own license in the first place?

Thy

rpavlik, 2018-11-04:
It's not really worth it to debate this at this point - it's perhaps not the greatest license but it's only for the hardware part, and open source hardware licensing is still fairly immature in general compared to the situation for software (few permissive, vs copyleft-style, licenses, no overwhelming precedent, and a totally different legal background - copyright not really being as important for a finished product, compared to, e.g. patents), and was even more nebulous when the hardware files were released years ago. It's not really a custom license - it's basically the license for the (ill-fated) Google Project Ara modular smartphone effort. (And as such, is a bit more stringent than you might expect, due to plans to comply with rf regulatory frameworks,etc)

In any case it doesn't affect you if you're using the hardware, or even modifying the firmware: basically everything except the physical bits are Apache 2.0. (the tracking hardware and firmware is Apache2 as well...) Even with any perceived flaws in the hardware license, the hardware is still more open than the vast majority of other HMDs out there, and these releases played an important part in setting standards and moving the industry forward.

ShalokShalom, 2018-11-04:
> it's perhaps not the greatest license but it's only for the hardware part

:roll_eyes:

Closed 2018-08-11.

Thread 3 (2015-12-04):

Can't open brd files

jack-vrstudios, 2015-12-04:
I am trying to use Eagle 7.4.0 Light Edition to open the brd files, but I get the "Start tag expected" error that usually means the file was generated with a different software.  What software did you use to generate the brd files?

rpavlik, 2015-12-05:
It looks like they were made with Cadence Allegro - at least, I could get them to open with a reader for that. In any case, the main board is 12 layers, and IIRC the free version of Eagle limits you to 2 right? I'm not terribly well versed in the EDA software market or file formats, or whether there's a better interchange format to use.

I agree this should at least be documented better, it took me a bit of digging to figure out how to open the files.

ohmahgawditbob, 2016-12-16:
Is there anything I can use to open/print for photoresist etching Cadence Allegro boards without paying insane amounts of money and without having to search for 5 years to find the download site?

Kasijjuf, 2016-12-16:
Will KiCad work? http://kicad-pcb.org

godbyk, 2016-12-16:
You should be able to view the files with the free [Cadence Allegro Viewer](https://www.cadence.com/content/cadence-www/global/en_US/home/tools/allegro-downloads-start.html).

rpavlik, 2016-12-16:
FWIW, it's a 6-layer board, fabricating it yourself may be a bit beyond DIY photoresist etching. But yes, the only thing that opens it is the Cadence Allegro Viewer (unless you have another $$$ EDA tool that can import those files).

I think there are Gerber files in there for at least some of the revs, though, which are what you'd need for production.

Closed 2016-12-30.

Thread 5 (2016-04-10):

Excel file for materials list won't open in excel.

KK4BitsPerSecond, 2016-04-10:
HDMI_T30I_S2_BOM_final-0118.xlsx won't open. When I try to open it, excel just freezes.

MulanVR, 2016-04-10:
I can open it with no problems from multiple PCs and OSes and also from my phone just now.
Which version of excel are you using?

KK4BitsPerSecond, 2016-04-10:
MS Office 2013 is giving me fits. It opens just fine in Numbers, I just tried it on my phone. Weird.

Closed 2016-04-15.

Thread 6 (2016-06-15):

No PDF schematics for HDK 1.3?

rpavlik, 2016-06-15:
There are fairly complete sets of PDF schematics for the 1.2, and a few for 1.4 (just the belt box and HMD mobo - missing the IR board at least), but just the brd (Allegro?) and gerber files for the 1.3.

MulanVR, 2016-12-30:
1.3 and 1.4 units are sharing the same schematics.
Let me know if this is ok to close.

Closed 2018-11-03.

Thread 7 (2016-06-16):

IR board .brd file for HDK 1.3 does not appear to match shipped unit

rpavlik, 2016-06-16:
Using the Cadence free physical viewer, I looked at the IR Board .brd file for the 1.3, but it appears to be missing the protruding section with the P5 programming header found in my 1.3 unit, which I was told was a standard production unit.

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

Continuity tests indicate it has the same pinout as the unpopulated P3 programming header, but the connector is undocumented, etc.

MulanVR, 2016-06-17:
Ryan, that's a 1.4 board. We gave you the newer board for testing in one of
our special prototypes for your contribution
The connector we changed based on ST link V2 programmer availability at
that time and the connector is documented in the mechanical file and in the
allegro library.

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

Closed 2016-12-30.

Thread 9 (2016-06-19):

HDK 1.4 COMPOUND object tears through COMPOUND002

Conzar, 2016-06-19:
I'm looking into breaking the model apart for 3d printing.  I have noticed that the COMPOUND object tears through the COMPOUND002 object.  This will be a problem during 3d printing.  I think the COMPUND object needs several of its vertices to be raised on the z-axis.

I have imported this via freecad and here is a screenshot.
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

Conzar, 2016-06-19:
Please disregard, I think there was an error in freecad.  After reloading the file, this issue has been resolved.

Closed 2016-06-19.

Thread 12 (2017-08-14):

How To Obtain Technical Specifications For OSVR HDK 1.4 Lenses?

Balderick, 2017-08-14:
Am struggling to convert individual components of osvr hdk using the provided .STP assembly drawing to .stl  files to determine parameters involved for production of osvr hdk 1.4 lenses.    The main problem is that I do not have access to professional grade cad tools.

Could .stl files be provided for all osvr hdk 1.4  parts additional to the .STP assembled working drawing?

Is there a any non premium software that can be used to convert .STP to .stl so that production parameters can be obtained for osvr-hdk modules?

I am trying to use steamvr tracking hdk software tools along with osvr-hdk, openscad, meshlab and blender to create a hmd using an adapted vive tracker  openvr driver to provide an openvr driver that takes care of all distortion as well as sensor fusion additional to steamvr tracking using osvr hdk.

I use stpviewer to view the provided .STP files but it can not convert modules to .stl

Where can I find the production tech specs showing parameters and tolerances for osvr hdk 1.4 lenses?

Is there any technical information available regarding how lense tech specs were calculated and for the configuration of them with osvr hdk 1.4 display?

Balderick, 2017-08-22:
osvr-docs

Closed 2017-08-22.

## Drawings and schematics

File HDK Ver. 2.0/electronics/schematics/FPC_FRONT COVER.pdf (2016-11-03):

# FPC-Front Cover Board 1/2

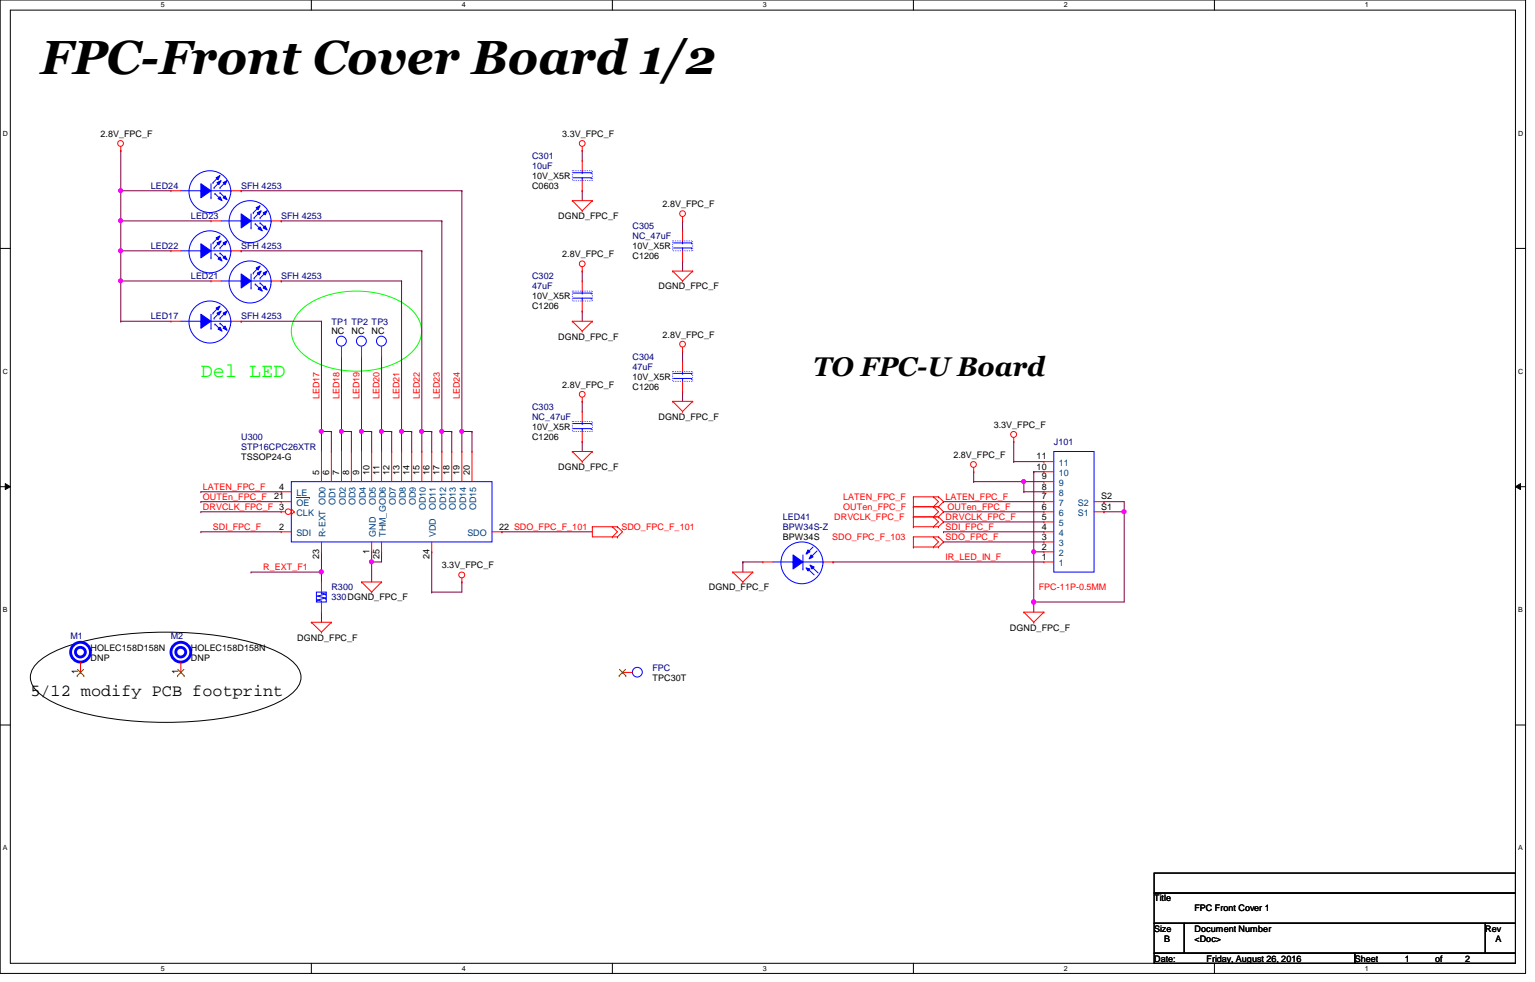
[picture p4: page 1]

# FPC-Front Cover Board 2/2

### 2.8V_FPC_F

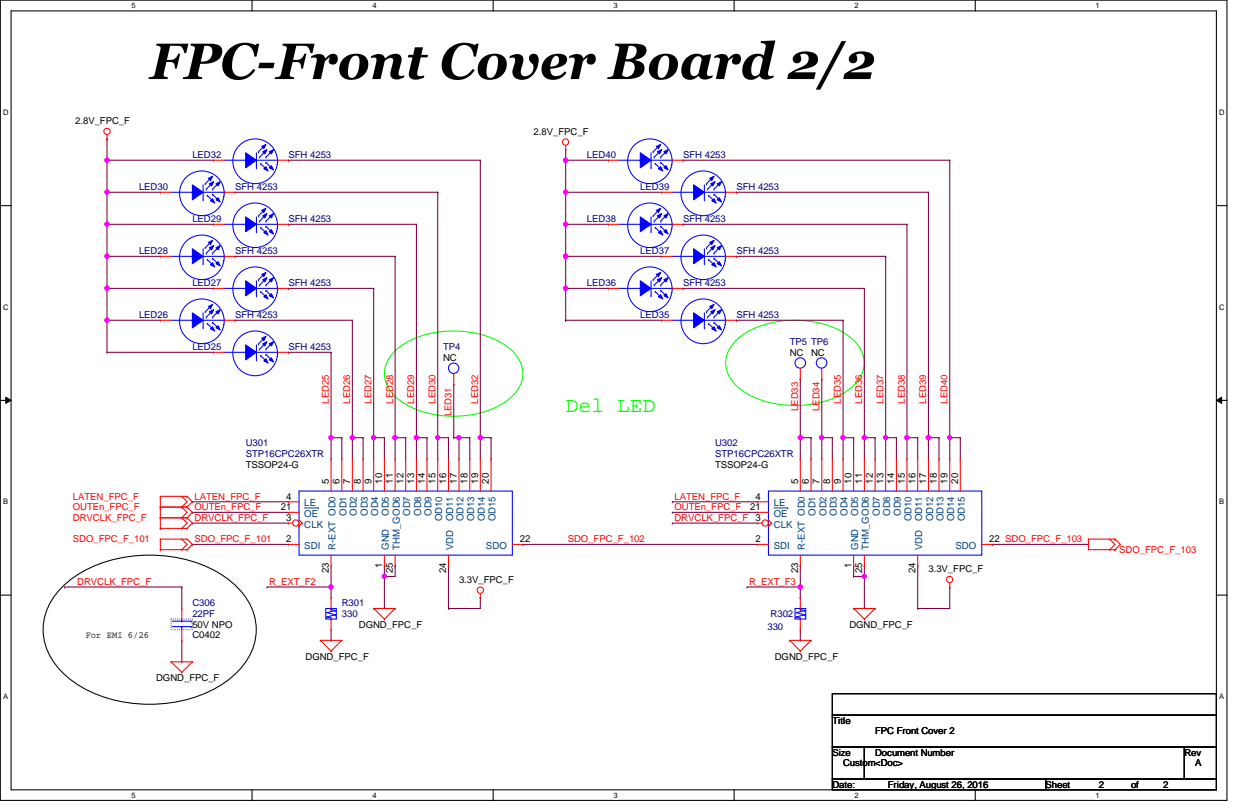
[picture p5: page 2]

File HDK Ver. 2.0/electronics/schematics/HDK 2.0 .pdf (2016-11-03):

# Eileen HDK 2.0 HMD BD SCHEMATIC

3

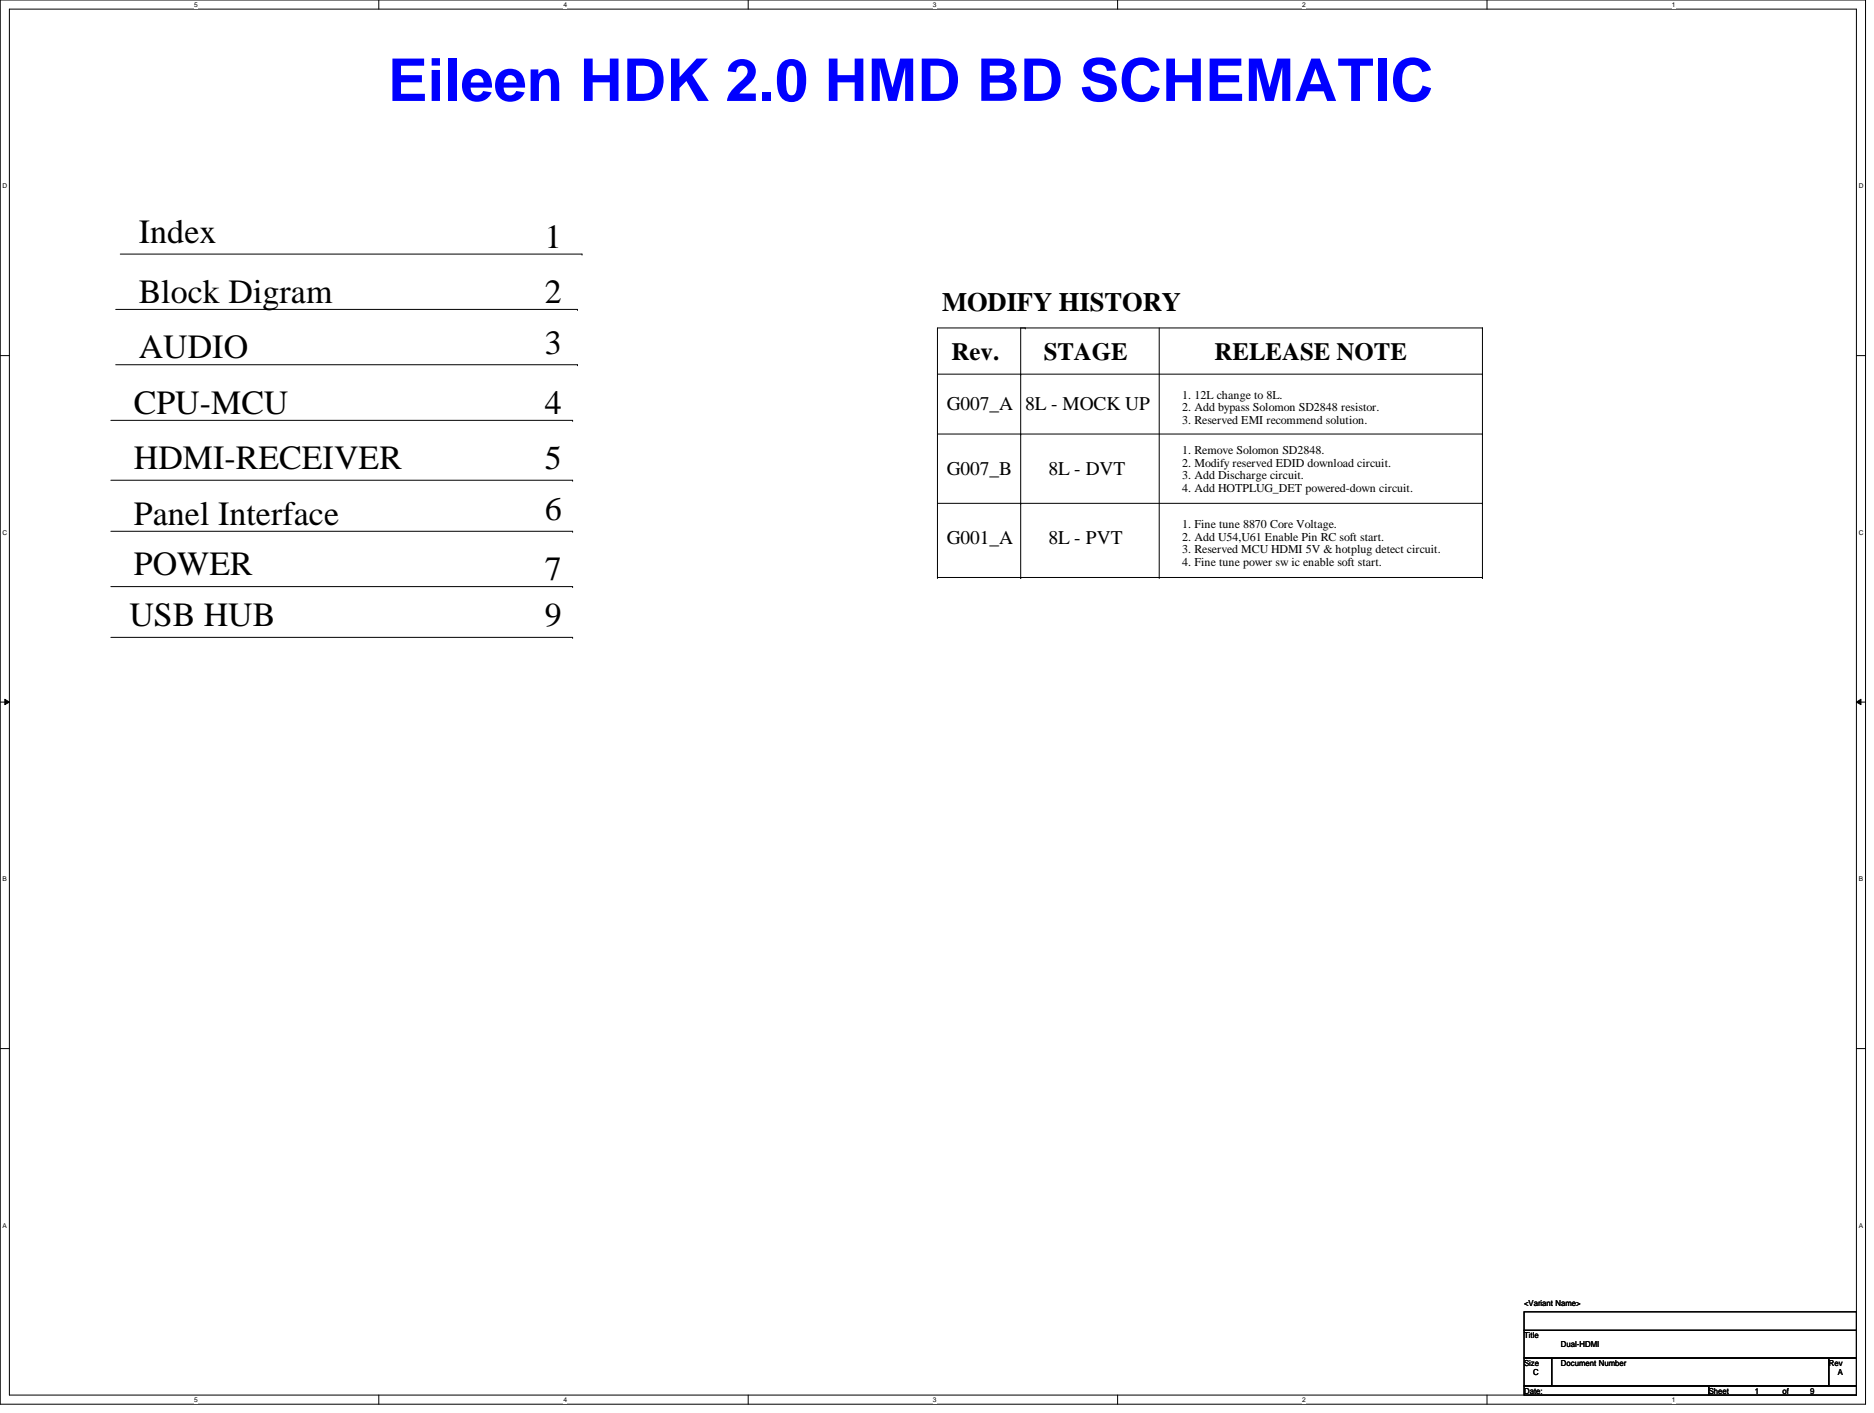
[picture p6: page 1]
USB HUB; AUDIO; Index; CPU-MCU HDMI-RECEIVER; Panel Interface; POWER; Block Digram; MODIFY HISTORY; Title; Size; Document Number; Rev; Date:; Sheet; Dual-HDMI; <Variant Name>

Rev. | STAGE | RELEASE NOTE

G007_A | 8L - MOCK UP | 1. 12L change to 8L. 2. Add bypass Solomon SD2848 resistor. 3. Reserved EMI recommend solution.

G007_B | 8L - DVT | 1. Remove Solomon SD2848. 2. Modify reserved EDID download circuit. 3. Add Discharge circuit. 4. Add HOTPLUG_DET powered-down circuit.

G001_A | 8L - PVT | 1. Fine tune 8870 Core Voltage. 2. Add U54,U61 Enable Pin RC soft start. 3. Reserved MCU HDMI 5V & hotplug detect circuit. 4. Fine tune power sw ic enable soft start.

# TOP

# HDMI Connector

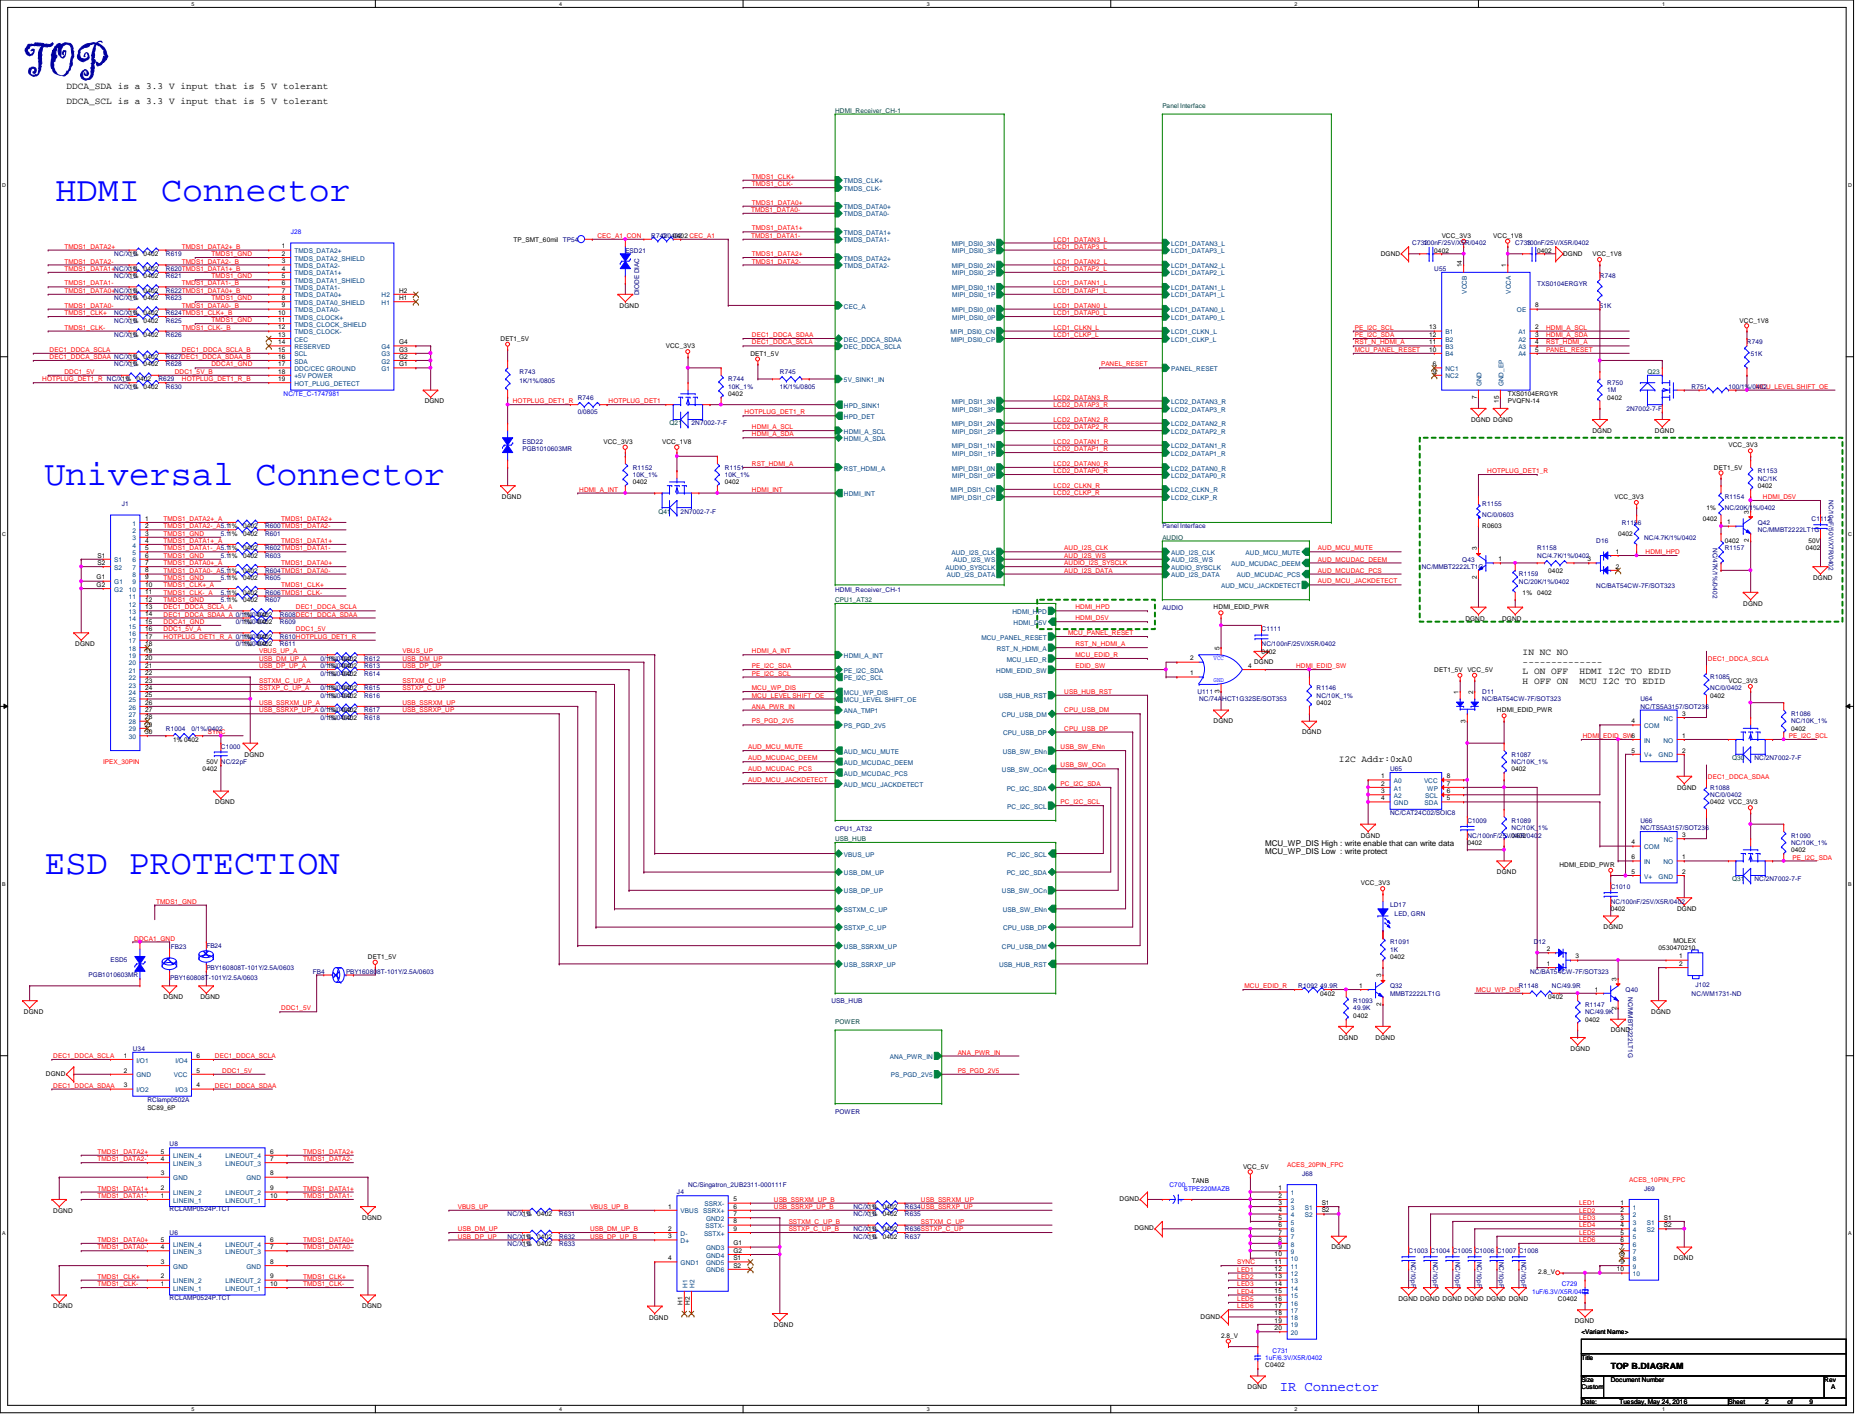
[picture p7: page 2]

DDCA_SDA is a 3.3 V input that is 5 V tolerant
DDCA_SCL is a 3.3 V input that is 5 V tolerant

HDMI_A_SDA HDMI_INT | LCD2_DATAP3_R LCD2_DATAN2_R

IN NC NO -------------- L ON OFF HDMI I2C TO EDID

H OFF ON MCU I2C TO EDID

MCU_WP_DIS High : write enable that can write data
MCU_WP_DIS Low : write protect

DGND DGND DGND

## DNP FB59 , C641 ,U50, R560, R561 C642

## DNP R461 R463 C576

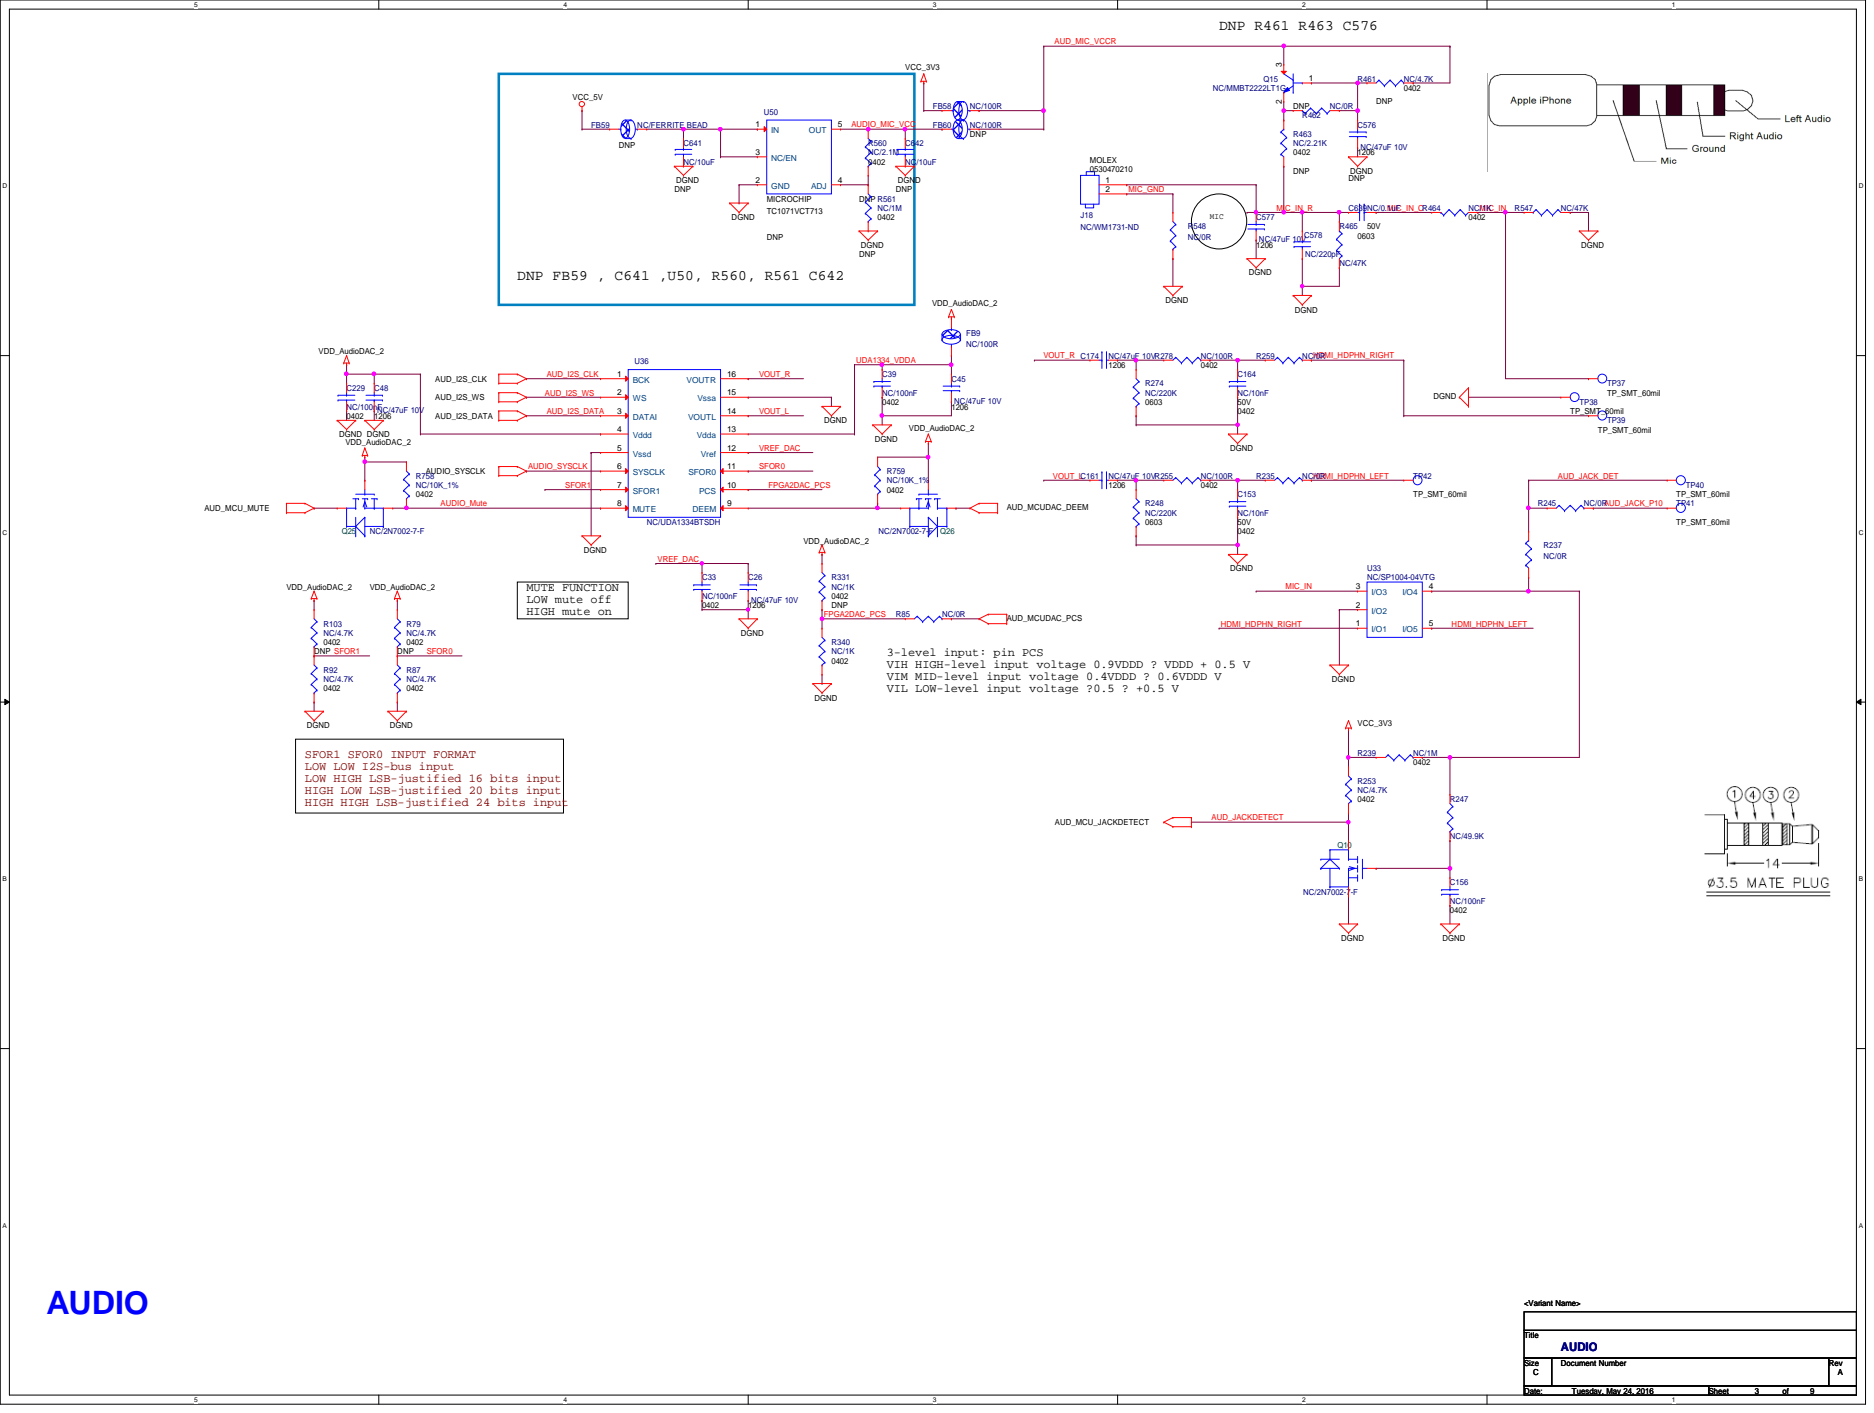
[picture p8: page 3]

3-level input: pin PCS
VIH HIGH-level input voltage 0.9VDDD ? VDDD + 0.5 V
VIM MID-level input voltage 0.4VDDD ? 0.6VDDD V
VIL LOW-level input voltage ?0.5 ? +0.5 V

SFOR1 SFOR0 INPUT FORMAT
LOW LOW I2S-bus input
LOW HIGH LSB-justified 16 bits input
HIGH LOW LSB-justified 20 bits input
HIGH HIGH LSB-justified 24 bits input

# C285100nF/25V/X5R/0402 0402

# C306100nF/25V/X5R/0402 0402

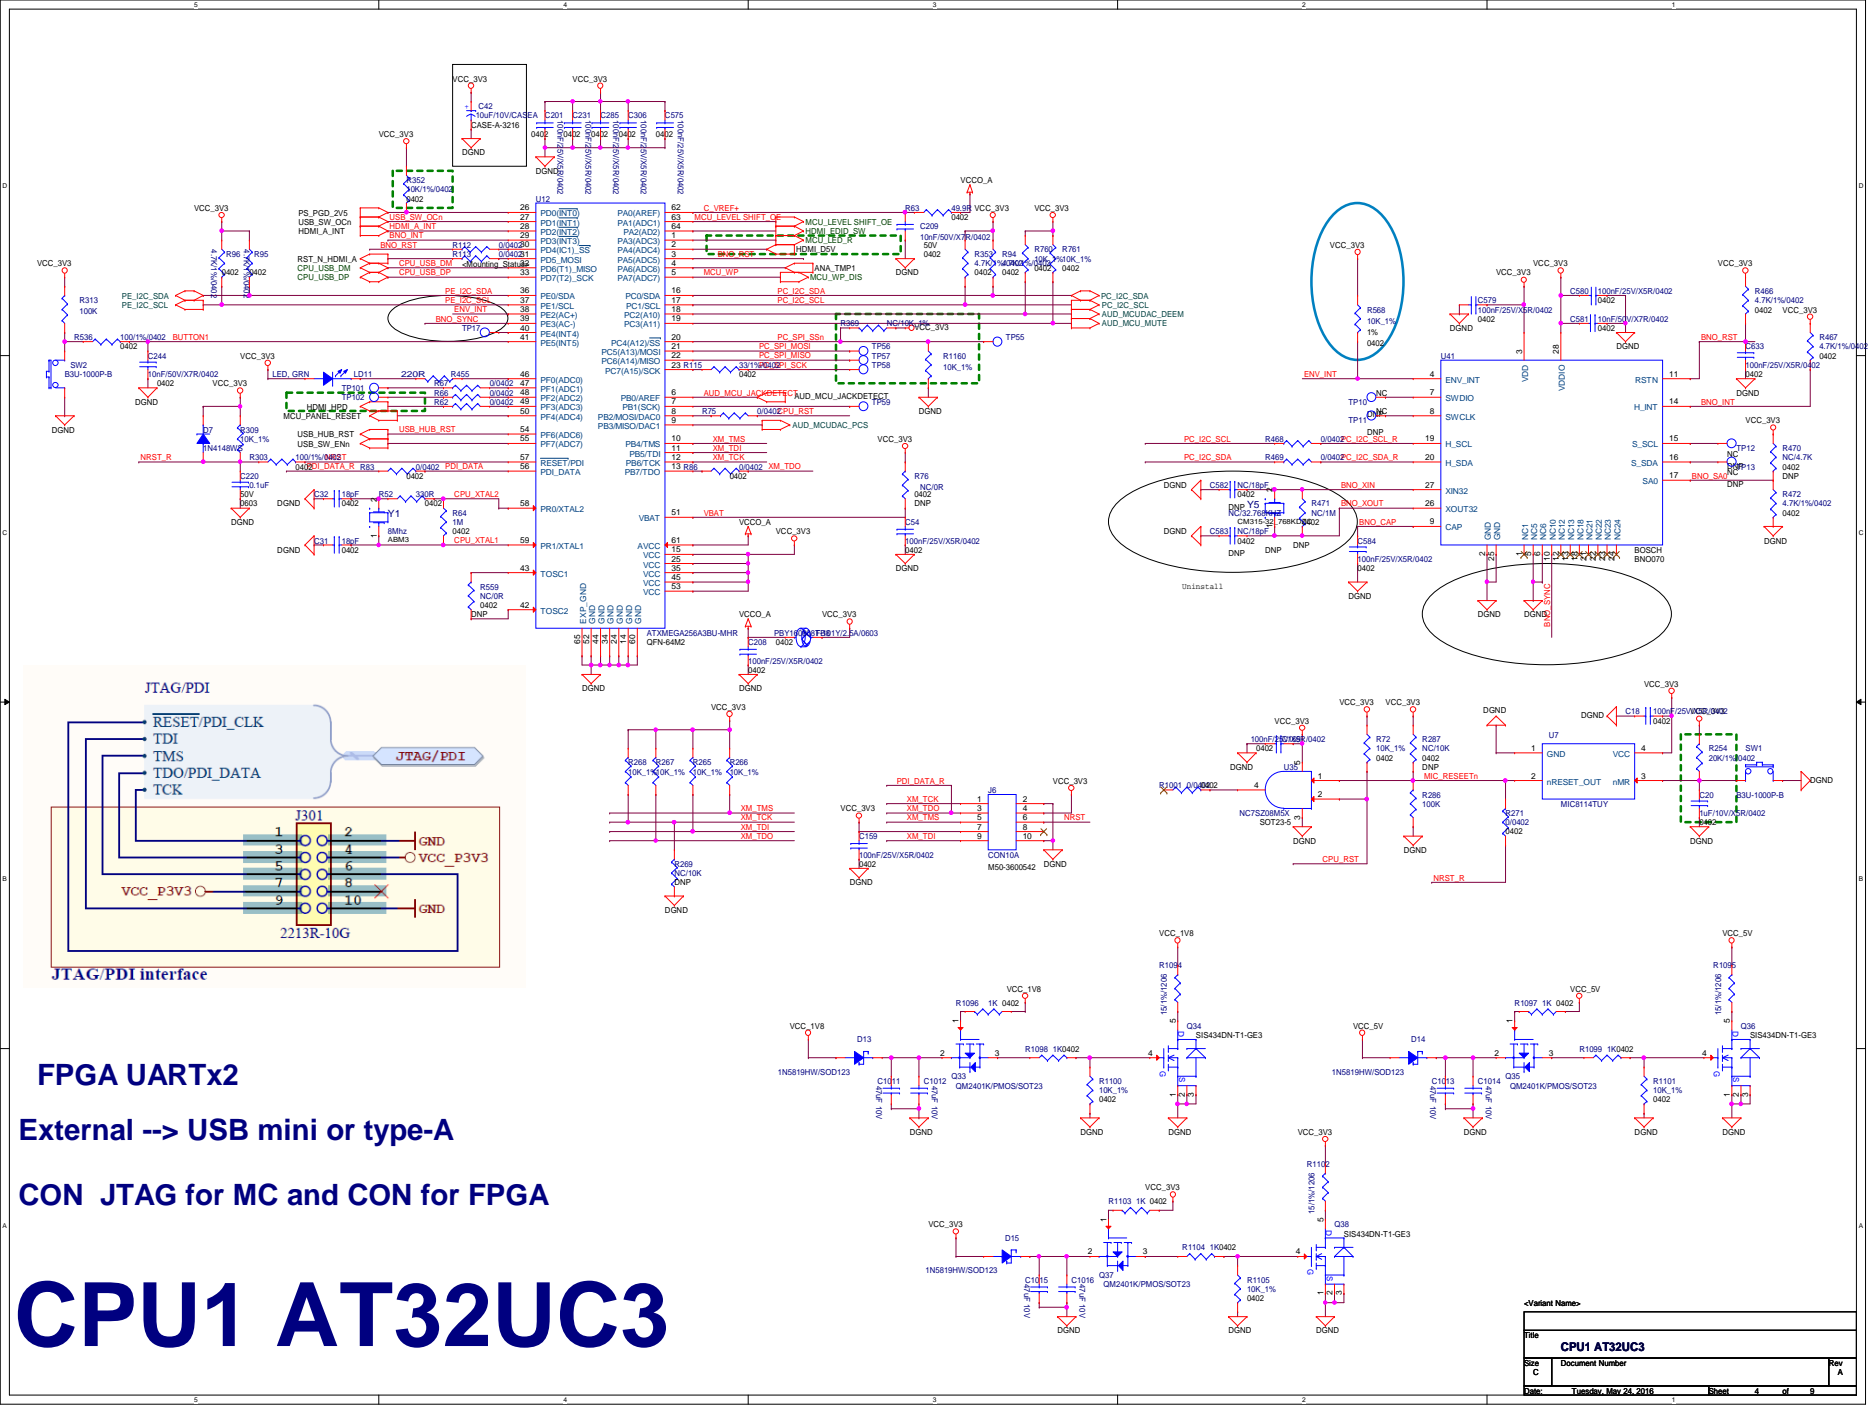
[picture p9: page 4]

FPGA UARTx2
External --> USB mini or type-A
CON JTAG for MC and CON for FPGA

### HPD_SINK1 HPD_DET

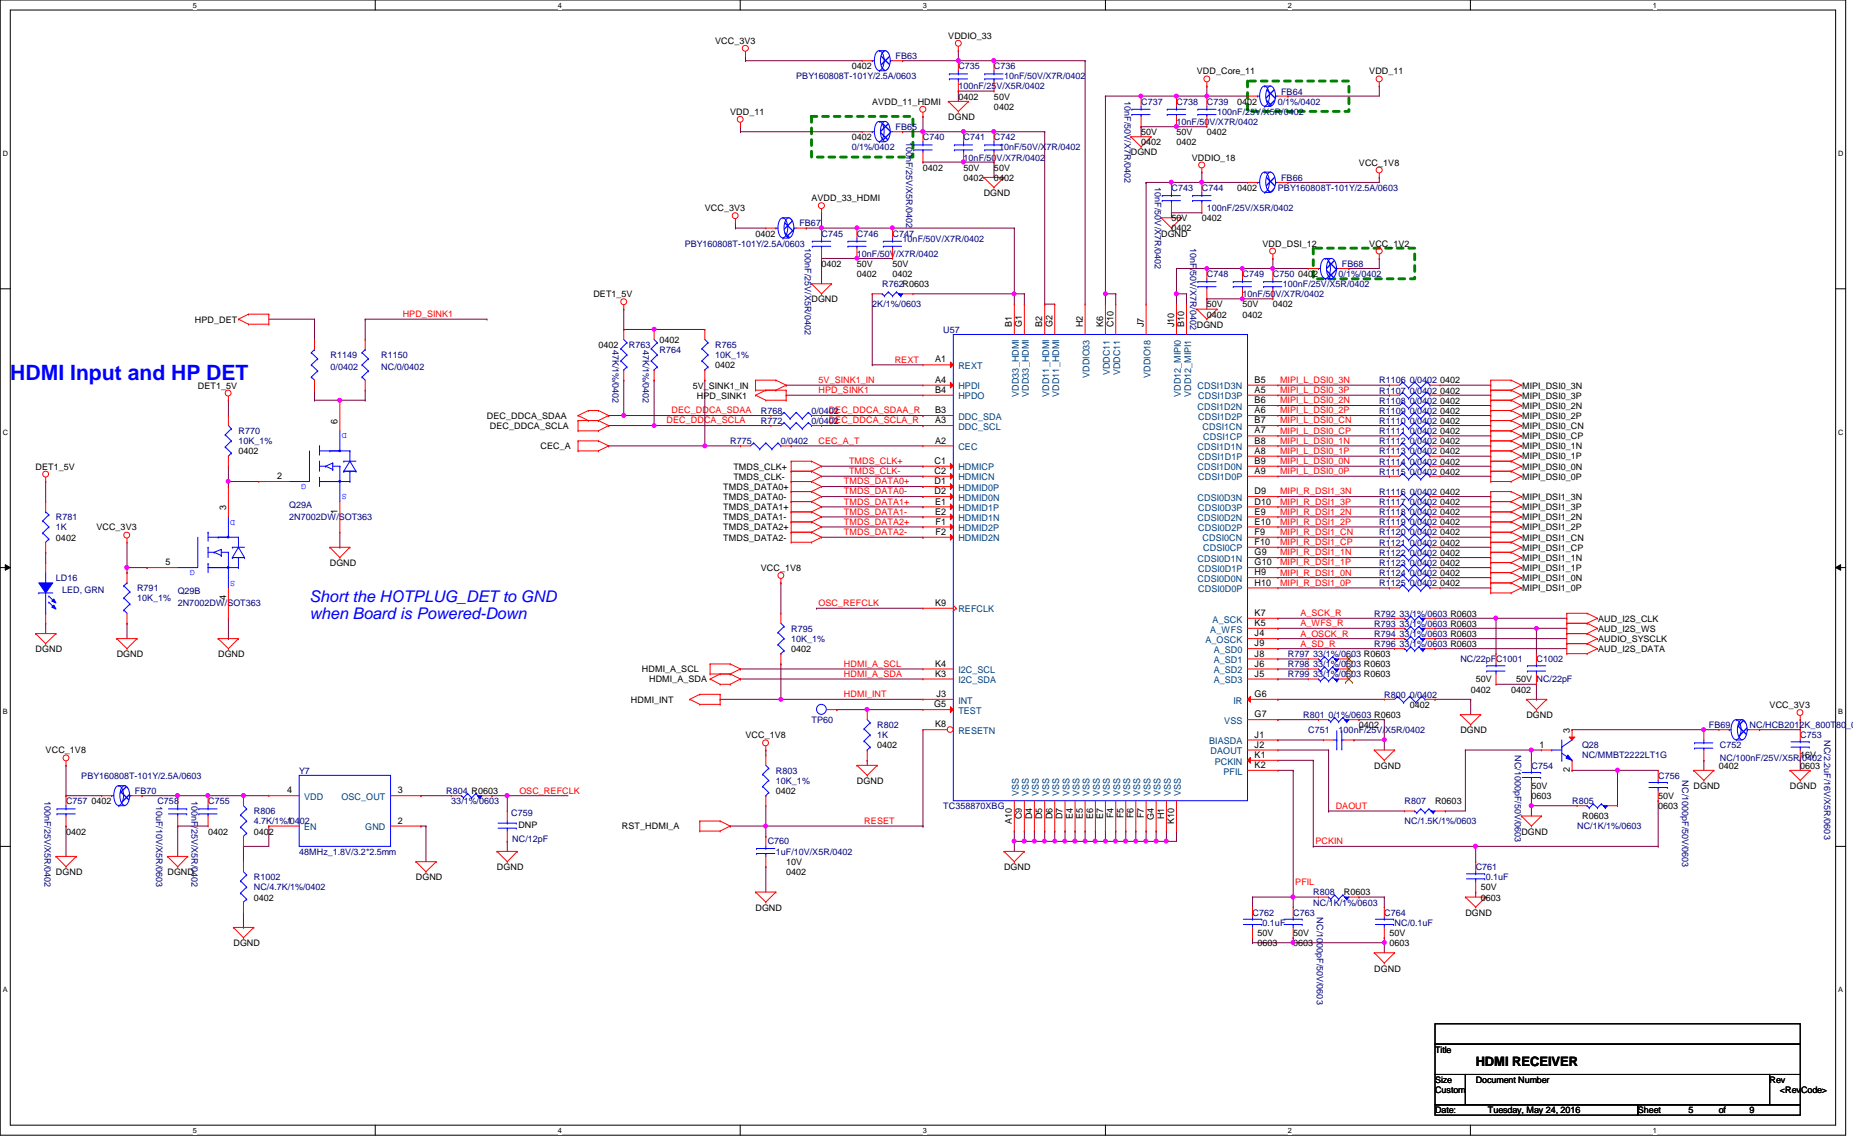
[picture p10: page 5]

HDMI Input and HP DET

DGND
Short the HOTPLUG_DET to GND
when Board is Powered-Down

3V 1.8V

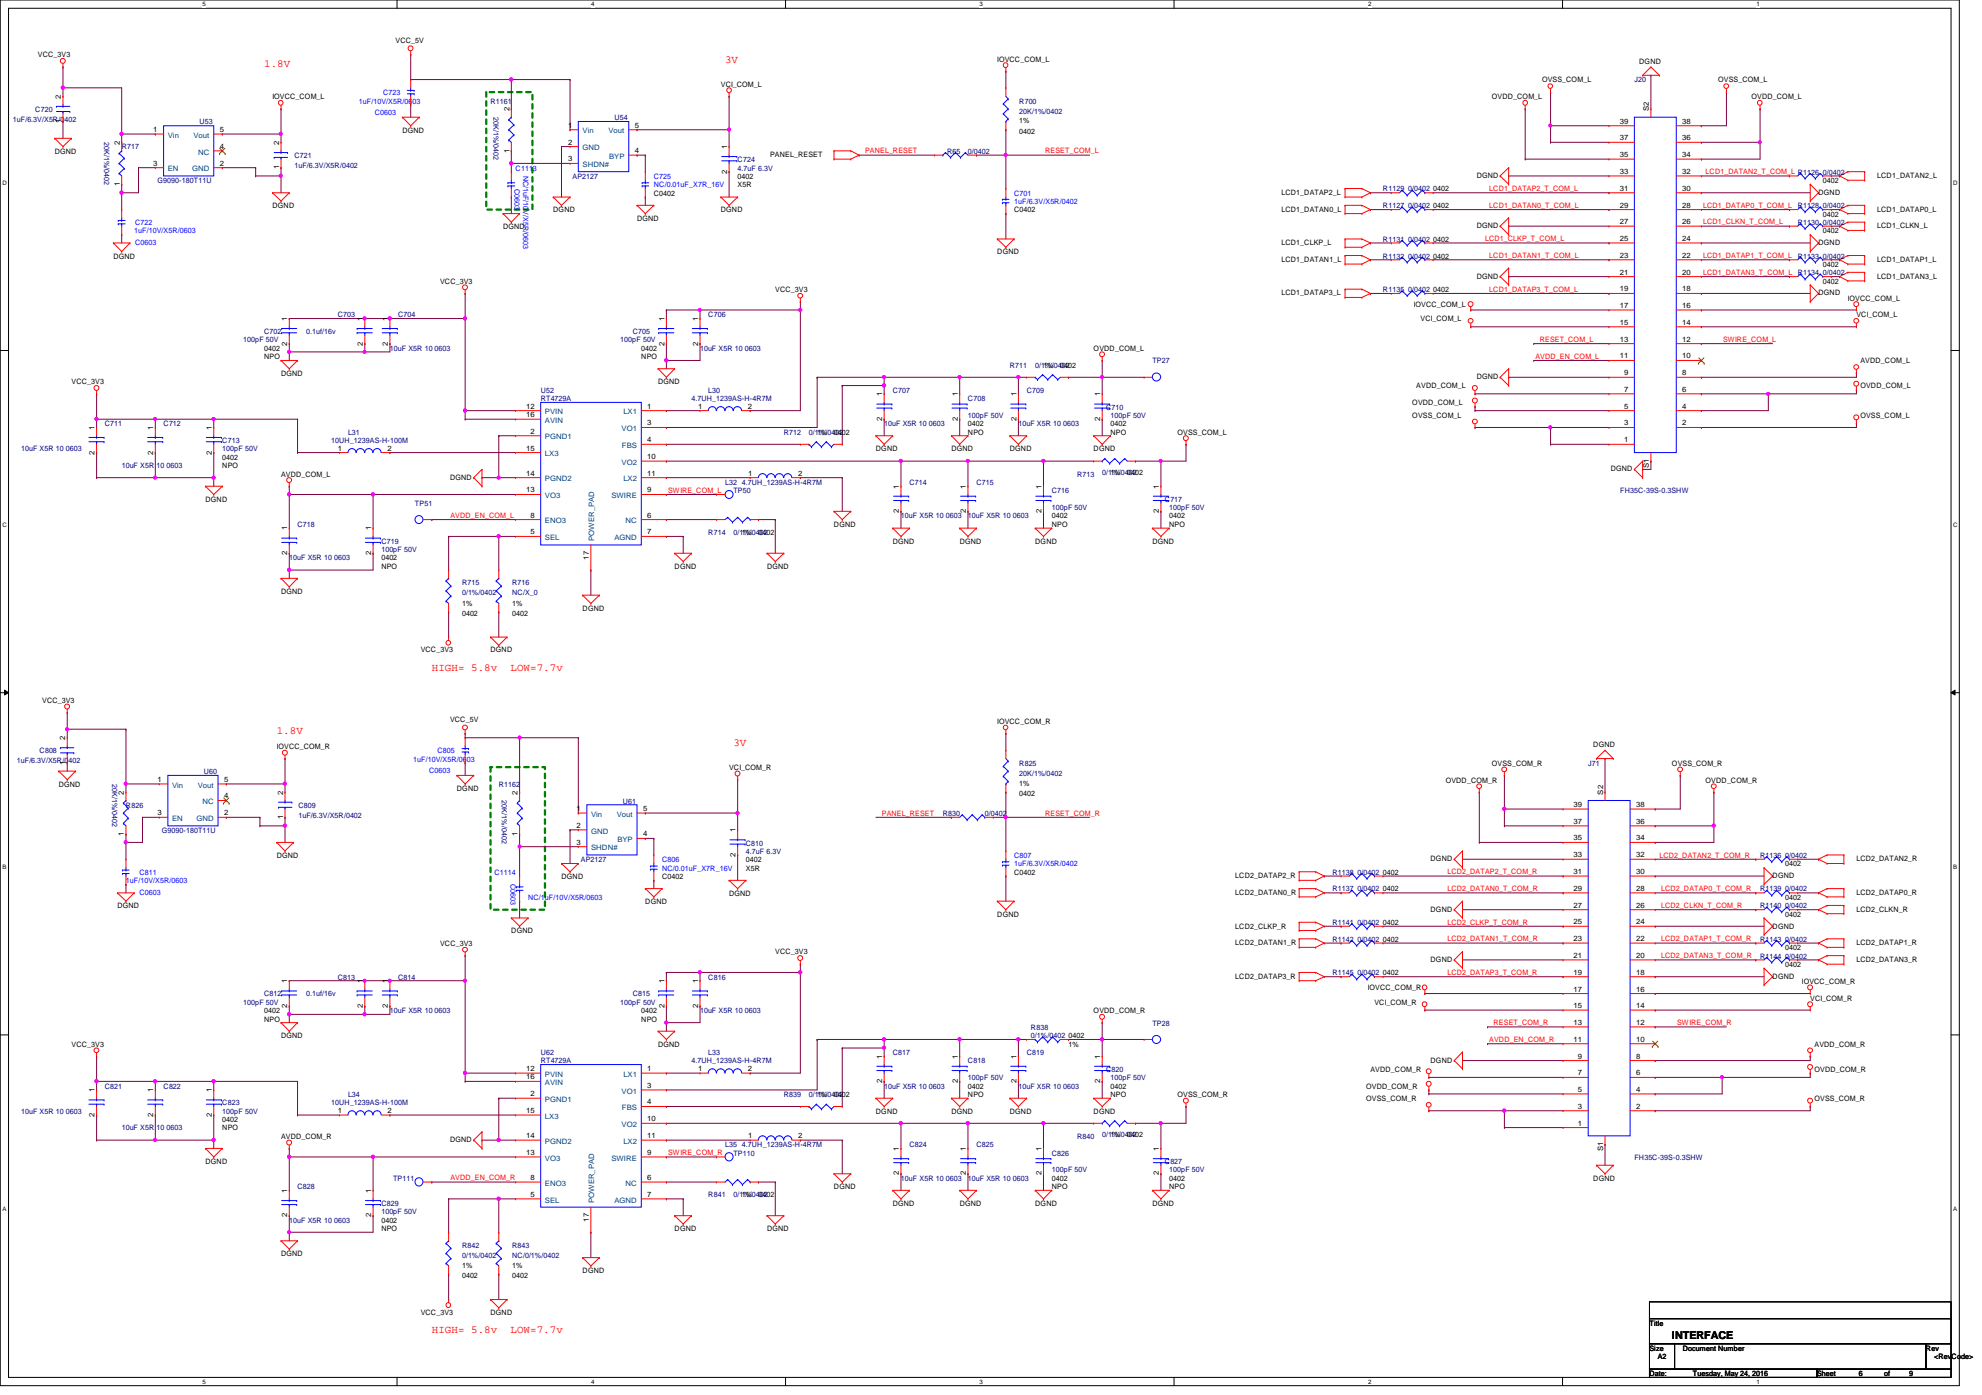
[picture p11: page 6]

## Reverse Voltage Protection

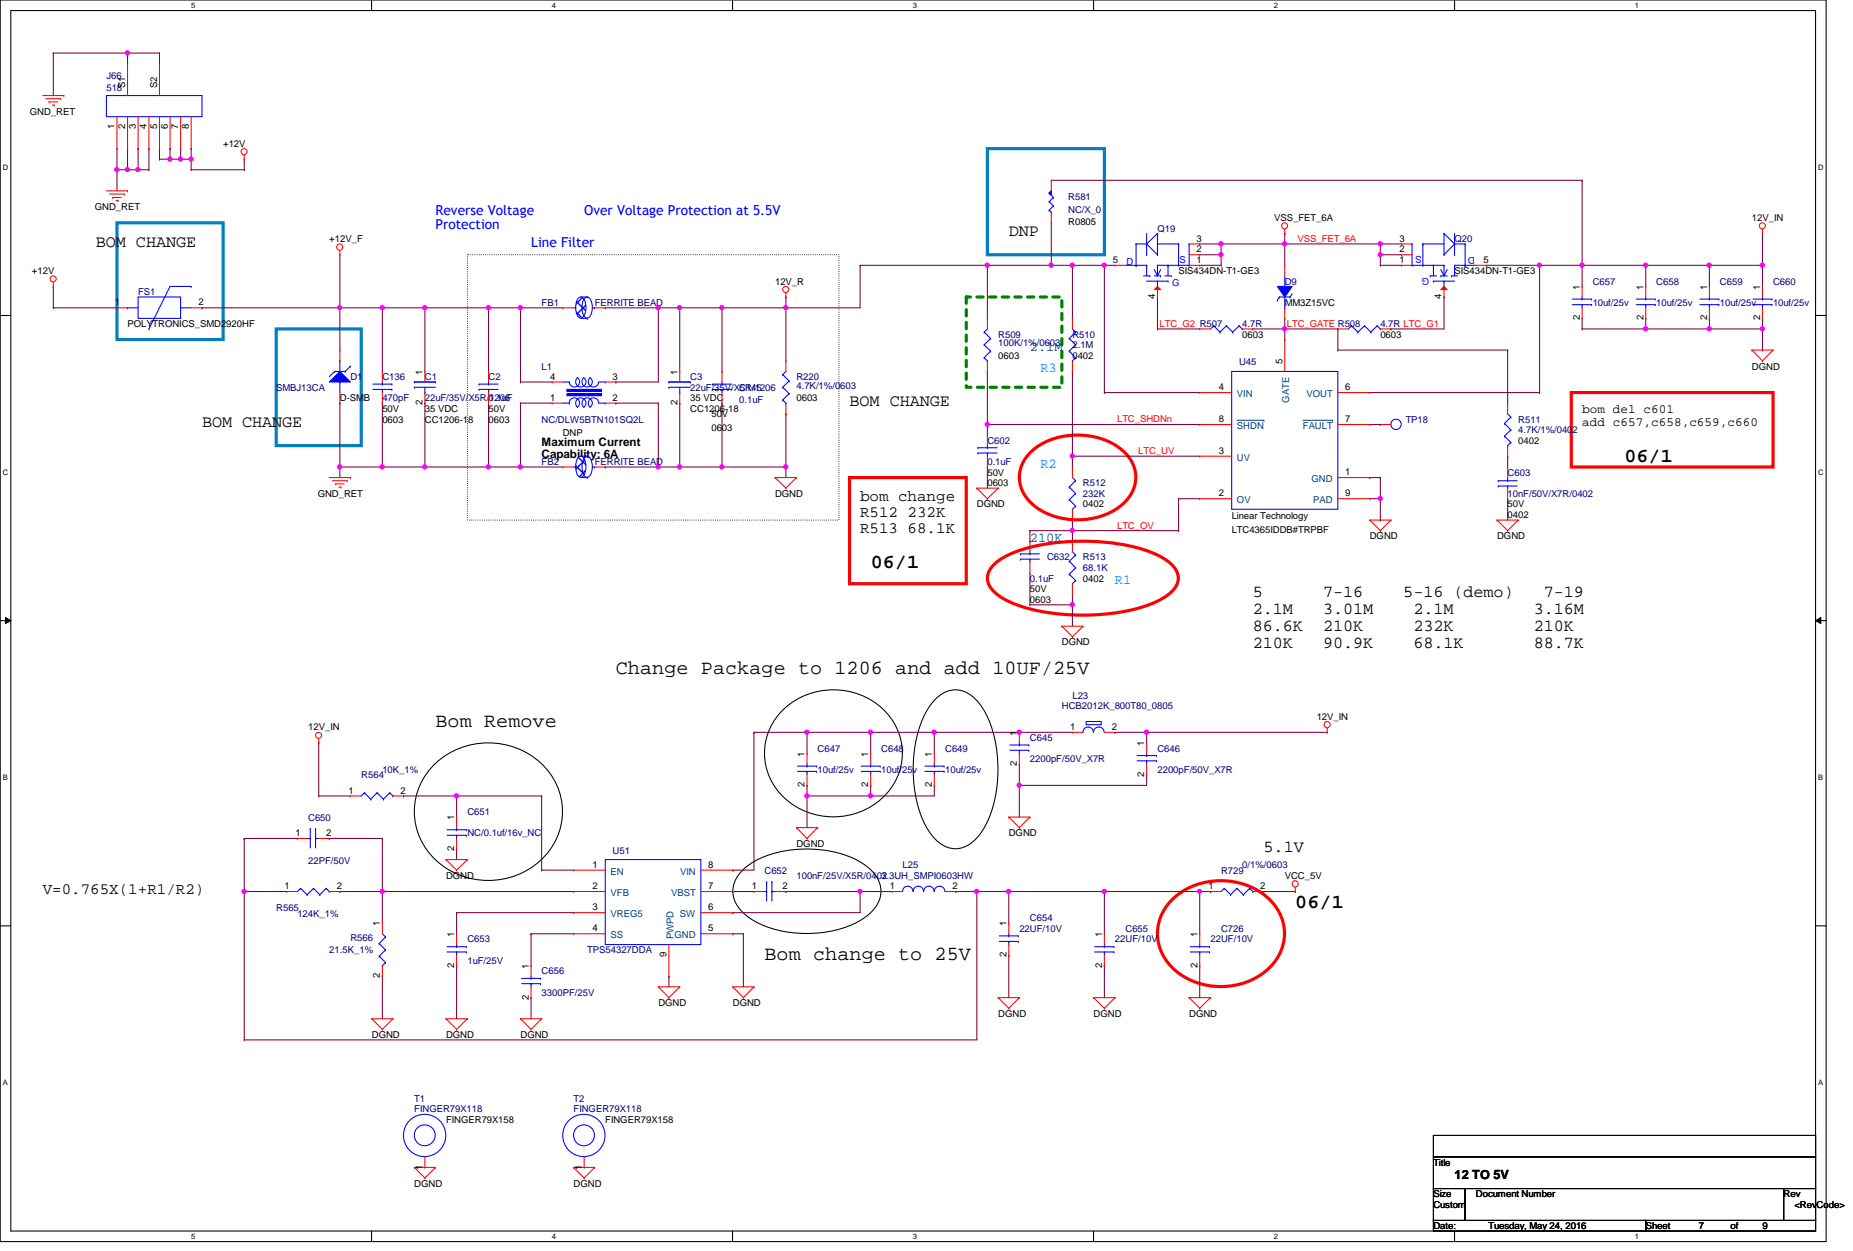
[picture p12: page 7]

Over Voltage Protection at 5.5V

Change Package to 1206 and add 10UF/25V

# POWER

## 0.6X(1+(R844+R845)/R846)

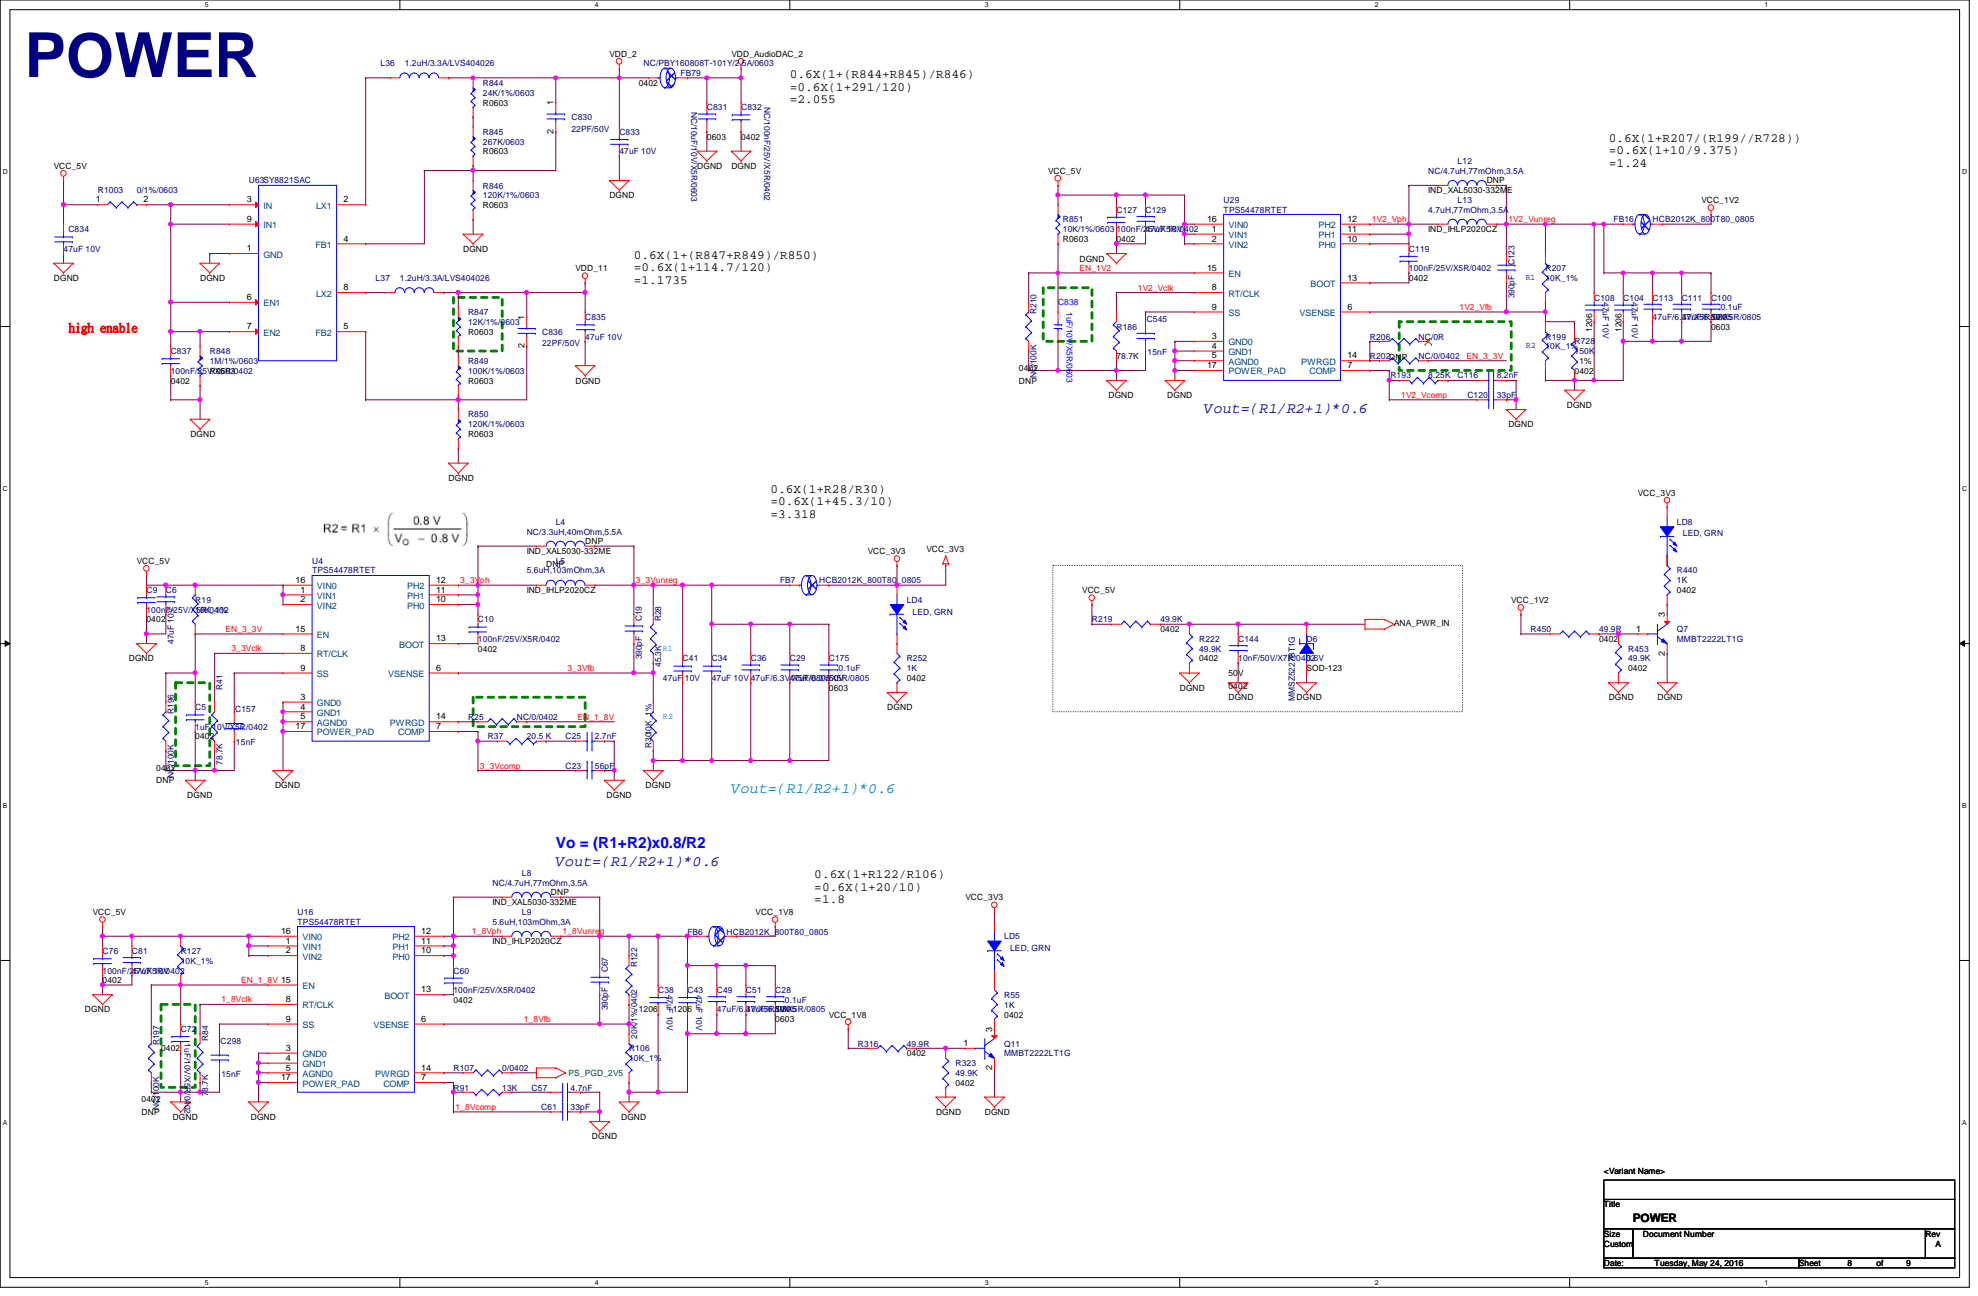
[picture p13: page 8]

## *Note that the SS signal pair Tx+/ are polarity

swapped on Jx for better routing.

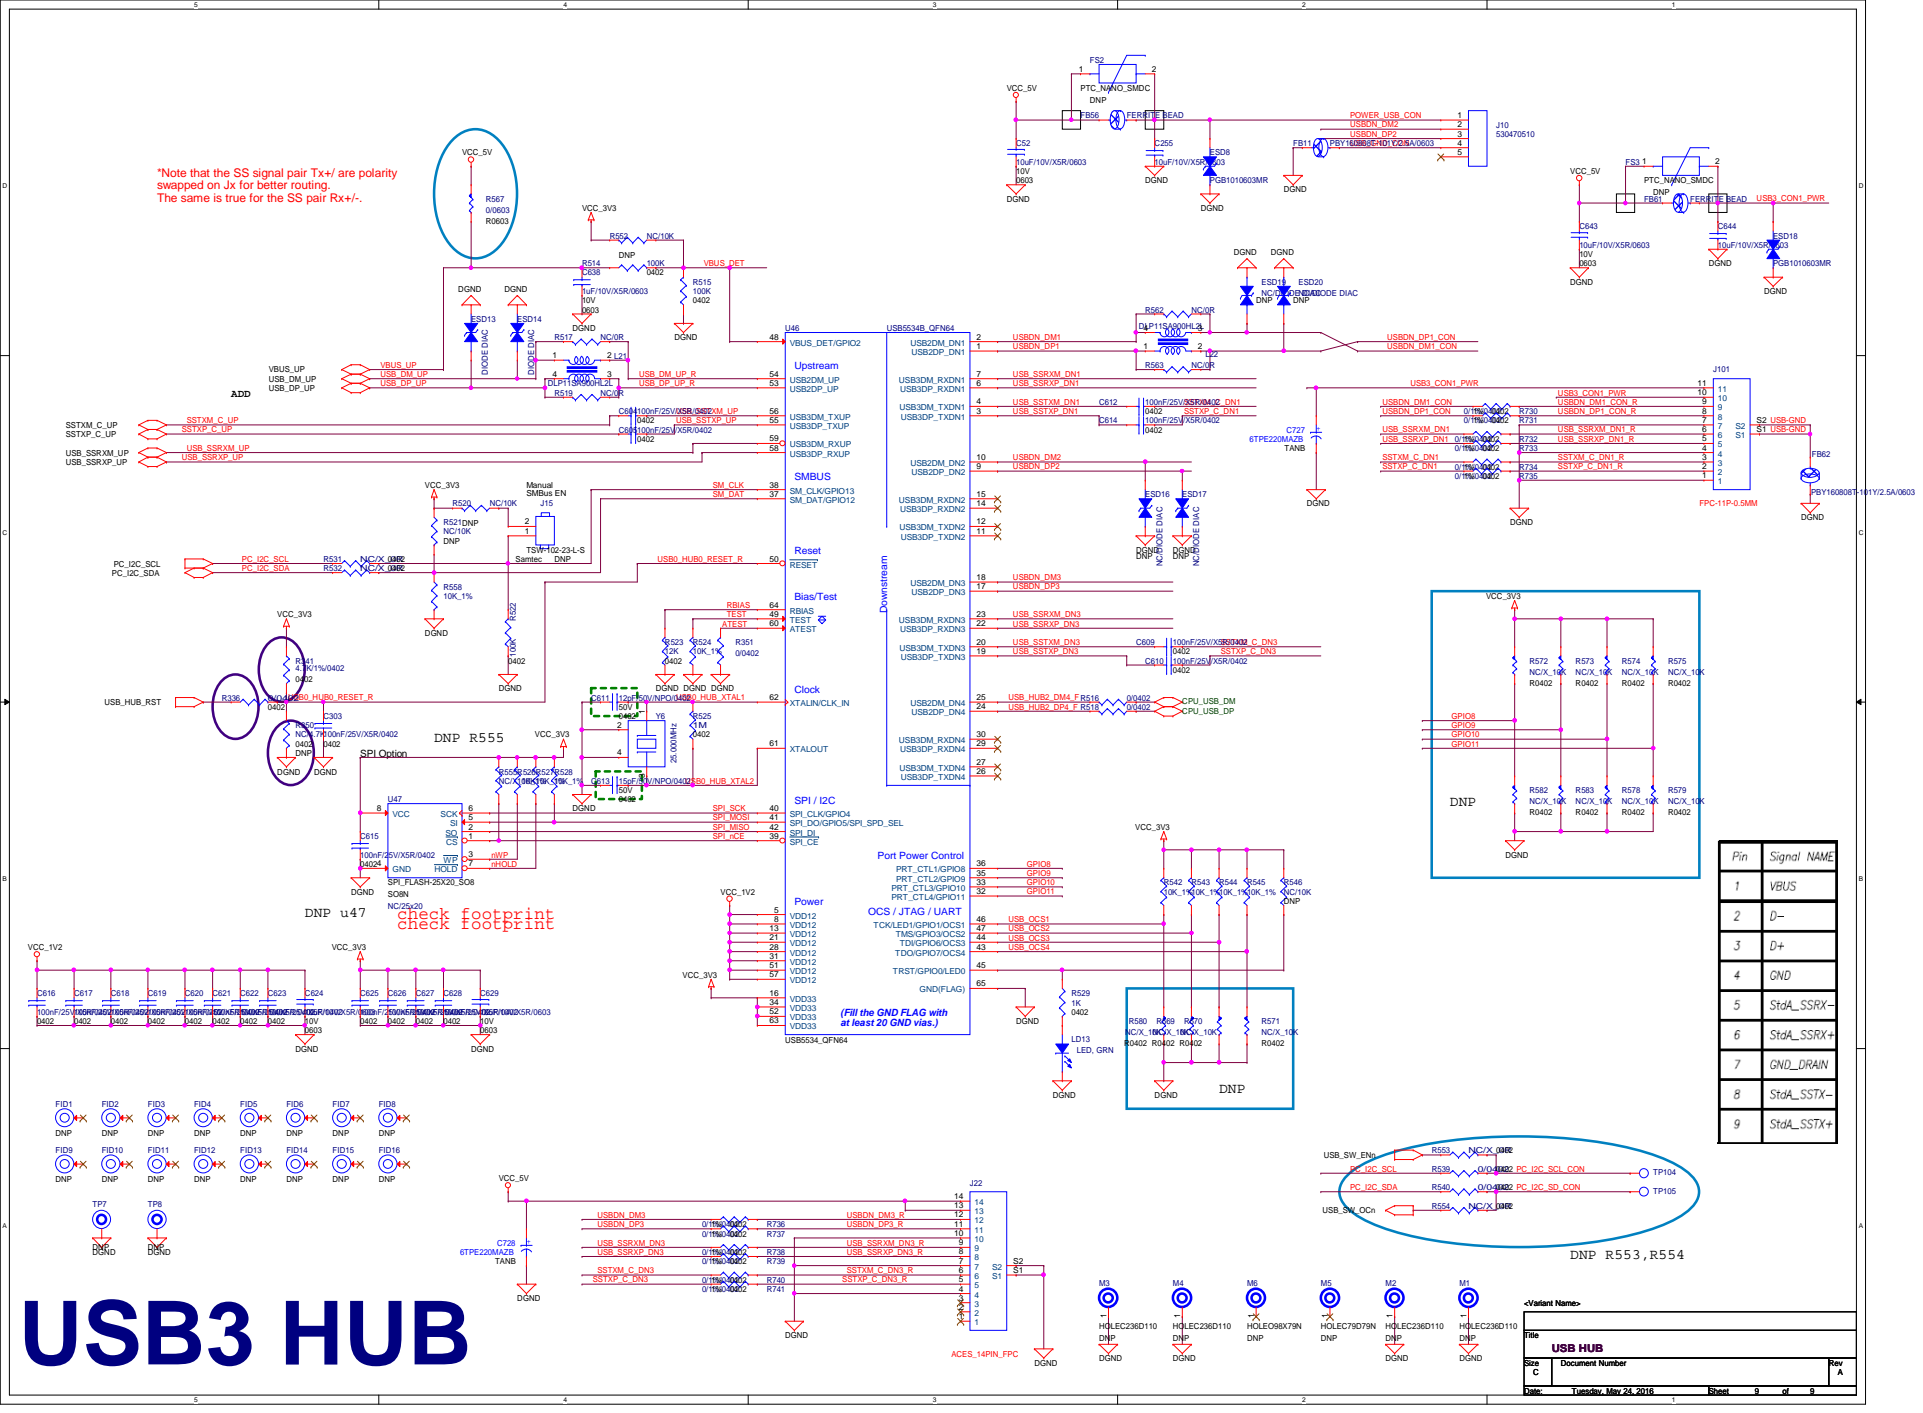
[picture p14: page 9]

The same is true for the SS pair Rx+/-.

NC/DIODE DIAC DNP

(Fill the GND FLAG with
at least 20 GND vias.)

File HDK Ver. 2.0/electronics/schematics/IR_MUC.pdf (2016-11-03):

# TO FPC_U Board TO HMD Board

# IR Board 1/4

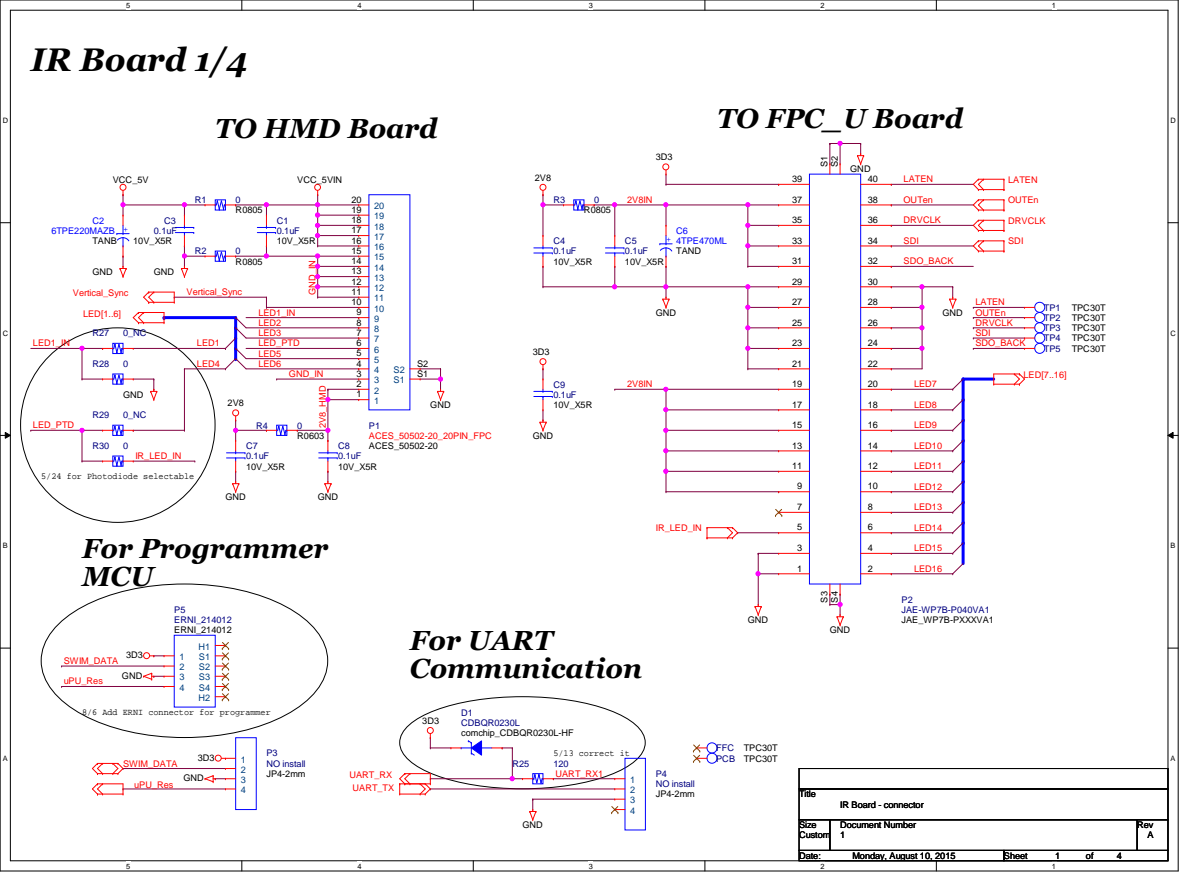
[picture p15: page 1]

8/6 Add ERNI connector for programmer

# IR Board 2/4


# IR Board 3/4


IR Board - LED Driver

# IR Board 4/4


PB7 9 PB6 10 I2C_SDA/ (T) PB5 11 I2C_SCL/(T) PB4 12 TIM1_ETR/AIN3/(HS) PB3 13 TIM1_CH3N/ AIN2/ (HS) PB2 14 TIM1_CH2N/ AIN1/(HS) PB1 15 TIM1_CH1N/AIN0/(HS) PB0 16

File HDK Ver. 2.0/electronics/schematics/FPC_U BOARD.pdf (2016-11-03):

TO IR Board | TO FPC_ Front Cover Board FPC-U board


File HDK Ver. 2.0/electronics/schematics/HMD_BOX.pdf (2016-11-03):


Add parts in bom FOR HDMI

## P_SPI_CK

## P_SPI_CZ


DV12 & AV12 power trace keep above 40 mils width

The circuits as close to Pin 1

## change to shortpad

## reference ckt is 100k ohm


data sheet is 0 ohm?
Vendor : use 100K ohm

Use 250mils wide trace bridging
AGND and DGND at codec.
See design guide.

shortage issue
change EEPROM to ROHM part

D | D

# Change Package to 1206 and add 10UF/25V


D | D

# HUB_RXN4


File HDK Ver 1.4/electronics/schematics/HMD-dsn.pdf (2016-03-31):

# VER-T31i_S2_Re_Single

# HDMI-Single

Title; Size; Document Number; Rev; Date:; Sheet; <Doc>; Dual-HDMI; <Variant Name>

# TOP

# HDMI Connector


DDCA_SDA is a 3.3 V input that is 5 V tolerant
DDCA_SCL is a 3.3 V input that is 5 V tolerant

HDMI_A_AP3 | AUD_FPGA2DAC_DEEM

HDMI_A_ACLK | AUD_FPGA2DAC_PCS

# DNP FB59 , C641 ,U50, R560, R561 C642

# DNP R461 R463 C576


3-level input: pin PCS
VIH HIGH-level input voltage 0.9VDDD ? VDDD + 0.5 V
VIM MID-level input voltage 0.4VDDD ? 0.6VDDD V
VIL LOW-level input voltage ?0.5 ? +0.5 V

SFOR1 SFOR0 INPUT FORMAT
LOW LOW I2S-bus input
LOW HIGH LSB-justified 16 bits input
HIGH LOW LSB-justified 20 bits input
HIGH HIGH LSB-justified 24 bits input


FPGA UARTx2
External --> USB mini or type-A

CON JTAG for MC and CON for FPGA
CPU1 AT32UC3

FPGA - Audio/Video Input from SDI Receiver (3.3V) | FPGA - Audio/Video & SDI Rx Ctrl Signals

## R400 repleace SBY100505T-470Y-N


* Address/CMD group: BA(2:0), A(15:0), RAS, CAS, WE
* Control group: CS, CKE, ODT
* Clock group: CLK0p and CLK0n
* Data group: DQ[12:0], UDQS, LDQS

Address /CMD group:
+-20mil between signals
Control group:
Clock group:
+-10mil between CLKn & CLKp
Data group:
+-20mil between DQ
+-10mil between LDQSn & LDQSp
DQS is longer than DQ

what is the power ref for the JTAG

# FPGA - DDR3 Interface (1.5V)

# DDR0_D11_FPAG-CH-1U30.A2

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

FPGA - Ground and NC pins

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

# DDR0 MEMORY INTERFACE

## DDR1_DQ12_FPAG-CH-1U29.C2


CHECK TERMINATION SIGNALS CLK AND

# HDMI RECEIVER PORT A


VDDIO(3V3) 32 VDDIO(3V3) 41 VDDIO(3V3) 50 VDDIO(3V3) 55 R289 10K

HDMI Input and HP DET

Short the HOTPLUG_DET to GND
when Board is Powered-Down


PS[1:0] is for SPI interface
- 00: 3 wire 24 bit SPI interface
- 01: 3 wire 8 bit SPI interface
- 10: 4 wire 8 bit SPI interface
- 11: SSL internal test mode

# Reverse Voltage Protection


Over Voltage Protection at 5.5V

Change Package to 1206 and add 10UF/25V

Size Size Size Custom Custom Custom | Document Number Document Number Document Number | Rev Rev Rev

Wednesday, September 16, 2015 Wednesday, September 16, 2015 Wednesday, September 16, 2015 | 10 10 10 12 12 12


## *Note that the SS signal pair Tx+/ are polarity

swapped on Jx for better routing.


The same is true for the SS pair Rx+/-.

VDD12 13 | USB_OCS2
VDD12 21 | USB_OCS3
VDD12 28 | USB_OCS4

(Fill the GND FLAG with
at least 20 GND vias.)

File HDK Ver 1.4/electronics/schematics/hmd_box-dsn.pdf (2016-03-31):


D | D

# USB3.0

USB HUB; USB_AUDIO; Connector; USB3.0; HDMI; Audio Connector; USB3.0 Connector; Repeter; POWER; Title; <Doc>; <RevCode>; <Title>

Size Custom Custom Custom | Document Number | Rev

Date: Wednesday, December 09, 2015 Wednesday, December 09, 2015 Wednesday, December 09, 2015 | Sheet 1 1 1 of 1 1 1

## P_SPI_CK

## P_SPI_CZ


TXN_DS4 38 TXP_DS4 39 GND5 40 RXN_DS4 41 RXP_DS4 42 VP12_5 43 DP4 44 DM4 45 DVDD12_1 46 PWREN2J 47 OVCUR2J 48 PWREN3J 49 PGREEN3 50 P_SPI_CK 51 P_SPI_CZ 52 PWREN1 53 PAMBER1 54 OVCUR4J 55 VBUS 56 DVDD1 57 AVDD_1 58 AVDD_2 59 PGANG 60 DVDD12_2 61 TEST 62 OVCUR3J 63 OVCUR1J 64 PGREEN1 65 P_SPI_DO 66 P_SPI_DI 67 PSELF 68 RESETJ 69 PGREEN2 70 V33 71 5V_1 72 PAMBER2 73 PGREEN4 74 PWREN4J 75 5V_2 76

DV12 & AV12 power trace keep above 40 mils width

The circuits as close to Pin 1

## change to shortpad

## reference ckt is 100k ohm


data sheet is 0 ohm?
Vendor : use 100K ohm

item11
Use 250mils wide trace bridging
AGND and DGND at codec.
See design guide.

shortage issue
change EEPROM to ROHM part

D | D

# Change Package to 1206 and add 10UF/25V


Size Size Size B B B | Document Number Document Number Document Number | Rev Rev Rev

Date: Date: Date: Monday, June 29, 2015 Monday, June 29, 2015 Monday, June 29, 2015 | Sheet Sheet Sheet 4 4 4 of of of 5 5 5

D | D

# HUB_RXN4


Size Size Size B B B | Document Number Document Number Document Number | Rev Rev Rev

Date: Date: Date: Monday, June 29, 2015 Monday, June 29, 2015 Monday, June 29, 2015 | Sheet Sheet Sheet 5 5 5 of of of 5 5 5






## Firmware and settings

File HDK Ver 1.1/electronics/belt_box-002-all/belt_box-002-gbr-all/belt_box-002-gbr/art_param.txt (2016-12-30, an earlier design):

DEVICE-TYPE           GERBER6X00
OUTPUT-UNITS          INCHES
FILM-SIZE             240000 160000
FORMAT                5.4
ABORT-ON-ERROR        NO
SCALE                 1
G-CODES               NO
OPTIMIZE              YES
STATIONS-PER-WHEEL    999
COORDINATES           ABSOLUTE
SUPPRESS-LEAD-ZEROES  YES
SUPPRESS-TRAIL-ZEROES NO
SUPPRESS-EQUAL        YES

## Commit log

2015-04-08 Initial commit.
    [Display board_BOM_0114.xlsx, HDMI_T30I_S2_BOM_final-0118.xlsx, HOUSING_FRONT_COVER_MB.STEP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]
2015-09-07 Front plate of HDK 1.2
2015-10-16 Schematics updates for HDK v1.2
2015-10-16 HDK 1.2 board files
2015-10-16 HDK 1.2 gerber files
2016-03-31 Updated Creo Cad files for hdk 1.2
2016-05-08 Power Supply spec file and plug details
2016-06-18 Expand all compressed archives into proper directories
    Make all the repo navigable on GitHub.com without having
    to download and extract nested layers of compressed archives.
    [053047-0210.psm, 0877591015_a3a-10pa.psm, 53047-0510.psm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]
2016-09-02 Folder re-organization to separate shipping configurations from legacy files
    [Display board_BOM_0114.xlsx, HDMI_T30I_S2_BOM_final-0118.xlsx, HOUSING_FRONT_COVER_MB.STEP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]
2016-11-03 Adding cable specs information
    [HDK 2.0 EE BOM summary v3.xlsx]
2016-11-03 Added complete schematics information for HDK2
2016-11-03 Reorganized Board files, including legacy files
    [DVT IR_PCB_BACK_0514.DSN, FPC_FRONT COVER_0425_16.DSN, FPC_U BOARD_0422_16.DSN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]
